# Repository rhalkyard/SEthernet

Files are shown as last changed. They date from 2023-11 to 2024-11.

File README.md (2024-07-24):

# SEthernet and SEthernet/30

Modern, low-cost 10/100 Ethernet for the Macintosh SE and SE/30.

## Introduction

It's an unfortunate reality of retrocomputing that, as time goes on, original
hardware only ever becomes more scarce, and usually more expensive.

While PDS ethernet cards are certainly not _scarce_ yet, the collector appeal of
Compact Macs means that cards are in high demand, with consequent high prices.
As of this writing (October 2023), the going eBay rate for them seems to be of
the order of $US 150-200, which is a bit steep for those of us who remember
finding them in electronics-recycler dollar bins.

While other projects have aimed to clone these original cards, such an approach
comes with a downside - the ethernet controller chips used in them have been out
of production for many years, and the controllers and (even more so) their
supporting components, are difficult to find.

While cloned cards trade off parts sourcing difficutly (and cost) for the
significant advantage of being able to use existing drivers, this project takes
the opposite approach: design an all-new card using a modern, readily-available
ethernet controller, and write a new driver for it. How hard can it be?
[^howhard]

## Hardware Overview

Both the SEthernet and SEthernet/30 use the Microchip
[ENC624J600](https://ww1.microchip.com/downloads/aemDocuments/documents/OTH/ProductDocuments/DataSheets/39935c.pdf)
all-in-one embedded ethernet controller. It's cheap, readily available, has a
straightforward software interface without too many glaring misfeatures (I'm
looking at you, RTL8019AS), and amongst its multitude of configurable host-bus
modes, it has one that matches the 68k processor bus nicely.

Since the Macintosh SE lacks any real infrastructure for expansion beyond
"here's a connector with the CPU bus on it," the SEthernet board is a very dumb
device. It simply maps the ENC624J600 into a vacant chunk of memory at `0x80
0000`-`0x80 ffff` and connects it to an interrupt line. Hardware detection,
interrupt vector interception, and device configuration are all left to the
driver to implement.

The Macintosh SE/30 is a more civilised machine, and the SEthernet/30 provides a
[declaration ROM](rom/se30) and multiple addressing options (configurable by
jumper) to take full advantage of the Slot Manager and coexist with multiple PDS
cards. Potentially, the driver could even be built into the declaration ROM,
allowing for a truly plug-and-play solution. To facilitate driver updates, the
declaration ROM is a flash chip, with logic to allow for in-system programming.

## Current project status

### Hardware

Hardware Revision 1 is largely 'done', and corrects the numerous issues of my
initial "Revision 0" boards. A few mechanical tweaks remain to get mounting
holes in exactly the right spot, and relocate connectors for easier access.

### Software

The core driver is functional and stable enough for everyday use. Real-world
performance is marginally better than a comparable vintage card, but there is
likely room to improve - especially in the rather convoluted receive routine.

Support for promiscuous mode, and the `ERead` call are not yet implemented.

The installer has some rough edges (no hardware detection or driver version
detection on the SE), but functions as a way to get drivers onto a system.

The SE/30 board's Declaration ROM must be programmed before the card can be
recognized. This can be done in-system using the
[programROM](software/tools/programROM/) application provided on the installer
disk, but right now this is a very ugly and user-unfriendly console application,
and really should be turned into a proper GUI app.

Testing has been done on my unmodified SE and SE/30 under Systems 6.0.8, 7.1,
and 7.5.5.

A driver for A/UX 2 and 3 can be found at
https://github.com/rhalkyard/SEthernet-AUX. 

## Project files

Schematics: [SEthernet](boards/se/se.pdf) -
[SEthernet/30](boards/se30/se30.pdf) - [Breakout Board](boards/breakout/breakout.pdf)

Glue Logic: [SEthernet](pld/se) - [SEthernet/30](pld/se30)

[SEthernet30 Declaration ROM](rom/se30)

[Driver](software/driver)

## Required tools

### Schematics, board layout and BOM

[KiCad 7](https://www.kicad.org/)

### Programmable Logic

[WinCUPL and ATMISP](https://www.microchip.com/en-us/products/fpgas-and-plds/spld-cplds/pld-design-resources)
(see [`pld/README.md`](pld/README.md) for notes on WinCUPL)

### Declaration ROM, driver and software

- [Retro68](https://github.com/autc04/Retro68) built with [Apple Universal
  Interfaces](https://github.com/autc04/Retro68#apple-universal-interfaces-vs-multiversal-interfaces)
  (at the time of writing, the default free-software Multiversal Interfaces do
  not include some necessary headers)

- [CMake](https://cmake.org/)

- [Python 3](https://www.python.org)

### Installer

- [hfsutils](https://www.mars.org/home/rob/proj/hfs/)

- [Python 3](https://www.python.org)

- [Mini vMac](https://www.gryphel.com/c/minivmac/index.html)

## License

The hardware components of this project ([board designs](boards/) and
[programmable logic](pld/)) are licensed under the [Strongly-Reciprocal CERN
Open Hardware License, version 2](CERN-OHL-S-2.0).

The [software components](software/) of this project are licensed under the [GNU
General Public License v3.0](COPYING).

While my choice to make this project open-source is very much a deliberate one,
I have a few further requests, on the basis of "I can't and won't enforce these,
but I'd appreciate if you respected them." It's unfortunate that I have to
mention this, but given how a few recent projects in the retro-hardware
community have splintered, I feel that it's necessary to say:

- Please don't sell cards commercially/for profit without checking with me
  first. I have plans for a sales and manufacturing partnership that will sell
  boards affordably, with full support. I don't mind if you order a batch of
  boards for yourself and sell the extras on a break-even basis, but please make
  it clear that these are not 'official' SEthernet products.

- Please contribute back, rather than simply forking the project. I strongly
  encourage people to modify the design, adapt it to other systems, integrate it
  into other devices. But unless what you're working on is a radical departure
  from the basic SEthernet design, I'd much rather see a unified, collaborative
  effort that is supported by a single software stack, rather than having it be
  fragmented.

If you have any questions, feel free to reach out to me, I don't bite!

## Useful reference material

- [ENC624J600 datasheet](https://ww1.microchip.com/downloads/aemDocuments/documents/OTH/ProductDocuments/DataSheets/39935c.pdf)

- [Designing Cards and Drivers for the Macintosh Family (3rd
  Edition)](https://www.vintageapple.org/inside_o/pdf/Designing_Cards_and_Drivers_for_the_Macintosh_Family_3rd_Edition_1992.pdf)

- [Inside Macintosh (1994): Networking](https://www.vintageapple.org/inside_r/pdf/Networking_1994.pdf)

- [Inside Macintosh (1994): Devices](https://www.vintageapple.org/inside_r/pdf/Devices_1994.pdf)

- [Glenn Anderson's ethernet driver page](https://www.mactcp.net/ethernet.html) -
  contains C source for a DP8390-based card.

- [Mac Driver Museum: Network
  Drivers](https://vintageapple.org/macdrivers/network.shtml) - good material
  for reverse-engineering. In particular, the Dayna ethernet drivers contain
  debug symbols, which are quite handy for our purposes.

- [Rob Braun's declaration ROM page](http://www.synack.net/~bbraun/declrom.html)
  has useful information about declaration ROMs and how they work.

[^howhard]: [Arrested Development narrator voice]: It was, in fact, quite hard

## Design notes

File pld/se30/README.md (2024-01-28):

# PLD Equations for 68030 PDS Interface

U3 on the SEthernet/30 board is an ATF1502 Complex Programmable Logic
Devices that provides address decoding and glue logic.

## Address Decoding

The SEthernet/30 board uses a Nubus 'pseudo-slot' design, occupying an address
corresponding to a NuBus slot, and appearing to the Slot Manager just like a
NuBus card would on a workstation Mac. To allow for multiple expansion cards,
jumpers JP1 and JP2 can be used to configure the card to act as though it is
installed in slots 9, A, B, or E.

Each slot has an interrupt line dedicated to it on the PDS connector, U3 routes
the ENC624J600's interrupt to the appropriate line based on the selection made
on JP1 and JP2.

Within the card's address space, minimal decoding is performed on address line
A16, so that the card's declaration ROM shows up at the top of the address space
(as expected by the Slot Manager), with the ENC624J600's address space
immediately below it.

Note that the Slot E configuration is not compatible with the SE/30 or IIsi.
This option exists to allow the card to be used in the PDS slot of a Macintosh
IIfx. This configuration has been tested and works, but the IIfx case does not
provide a place to mount the breakout board.

## Bus Control

While the ENC624J600 in PSP Mode 4 maps neatly onto the 68000's control lines,
glue logic is required to interface with the 68030. Page 7-26 of the [M68030
User's Manual](https://www.nxp.com/docs/en/reference-manual/MC68030UM-P1.pdf)
describes logic to interface the 68030 to peripherals using 68000-style
byte-select lines, a 16-bit subset of which is implemented in U4.

Additionally, U4 generates the `/DSACKx` signals for the 68030 bus handshaking
scheme. To accommodate the timing characteristics of the ENC624J600 (75 ns from
selection to data valid on read), a counter is used to delay assertion of
`/DSACKx` for 1 or 2 clock cycles after the chip is selected.

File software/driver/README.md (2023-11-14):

# Driver

The source this directory can build a Slot Manager `.ENET` driver for an SE/30
card, or a non-Slot Manager `.ENET0` driver for an SE card.

While the code for the two drivers is identical save for some differences in
device initialization and interrupt handling, the way Mac OS ethernet drivers
work means that they need to be separate driver resources.

## SEthernet/30

Slot Manager drivers such as the SEthernet/30 driver use `.ENET` as the driver
name in their resource header, and are installed as `enet` resources with a
Resource ID corresponding to the Board ID that they operate with. These drivers
can either be installed directly into the System File, or (with Network Software
Installer 1.5 or later) as Extensions with the type `comd`.

When an ethernet device is opened with `OpenSlot()`, the system `.ENET` 'driver
shell' searches `enet` resources for a driver whose resource ID matches the
Board ID of the slot, and loads that driver instead.

## SEthernet

Non-Slot Manager drivers must be installed as traditional drivers (i.e. a `DRVR`
resource) called `.ENET0`. This can either be done by manually installing the
resource into the System file, or loading the driver into the driver table at
run-time, for example, using an `INIT`.

Software that uses ethernet devices must try to load a `.ENET0` driver if no
Slot Manager devices are available. See Listing 1-11 in [IM:
Networking](https://www.vintageapple.org/inside_r/pdf/Networking_1994.pdf) for
details (and "Installing a Device Driver" in [IM:
Devices](https://www.vintageapple.org/inside_r/pdf/Devices_1994.pdf) for the
absurd song-and-dance routine that is installing and opening a device driver).

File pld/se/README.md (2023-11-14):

# PLD Equations for 68000 PDS Interface

U2 on the SEthernet board is an ATF16V8/GAL16V8 programmable logic device that
provides address decoding and miscellaneous glue logic.

Address decoding is straightforward - when `/AS` is asserted and address lines
`A24..A16` indicate an address in the range `0x80 0000`-`0x80 FFFF`, we assert
the ENC624J600's chip-select pin.

Glue logic is also minimal - the `B0SEL` and `B1SEL` byte-select lines on the
ENC624J600 are just active-high equivalents to the active-low `/UDS` and `/LDS`
lines on the 68000 bus. The BBU chip on the SE logic board automatically asserts
`/DTACK` for us on a schedule that we can live with, so there is no need to
generate it ourselves (if we needed additional wait states, we could assert
`/EXT.DTK` to suppress the BBU's `/DTACK` signal until we were ready).

Finally, the push-pull interrupt output of the ENC624J600 is buffered and turned
into an open-drain output, allowing it to interface with the wired-OR interrupt
logic of the SE.

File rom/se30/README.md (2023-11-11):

# Declaration ROM

To make use of the Slot Manager for hardware probing, interrupts, etc. we need
to do two things:

- Map our device into a memory region corresponding to a NuBus slot (on the
  SE/30, valid 'pseudoslots' are `9`, `A`, or `B`).

- Have a declaration ROM header at the very end of the slot's address space,
  pointing to a valid sResource directory.

This directory contains a suitable declaration ROM laid out in GNU Assembler
format, with a Python script to perform some basic validity checks and
post-processing.

## Files

`declrom.s`: Source for declaration ROM.

`ROMDefs.inc`: Assorted constants and macros for declaration ROMs, converted to
GNU Assembler format from Universal Interfaces file `AIncludes/ROMDefs.a`.

`declrom_macros.inc`: Additional macros for declaration ROMs.

`gencrc.py`: Quick 'n dirty Python script to sanity-check a declaration ROM
header, calculate and write the CRC field, and pad it to a suitable length to
program into an EPROM.

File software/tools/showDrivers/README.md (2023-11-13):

# showDrivers

A quick and dirty tool to list the entries in the system's driver table.

## Table columns

**Unit**: Driver unit number

**RefNum**: Driver reference number used for Device Manager calls (1's complement
of unit number)

**Flags**: Driver flags (explained below)

**DRVRAddr**: Address of driver's `DRVR` resource in memory

**Name**: Driver name

## Driver flags

Lowercase letter means flag is not set, uppercase letter means flag is set.

**L**: Driver is locked in memory

**T**: Driver performs periodic tasks

**G**: Driver needs to be called before application heap initialization

**S**: Driver responds to `Status` call

**C**: Driver responds to `Control` call

**W**: Driver responds to `Write` call

**R**: Driver responds to `Read` call

**A**: Driver is currently executing a request

**H**: Driver is referenced through a Handle, rather than a Pointer

**O**: Driver is open

**V**: Driver has marked itself as virtual-memory safe

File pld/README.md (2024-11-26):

# Programmable Logic Device Sources

The sources in this dirctory are in CUPL format, and can be built using the
Windows-based
[WinCUPL](https://www.microchip.com/en-us/products/fpgas-and-plds/spld-cplds/pld-design-resources)
software. Unfortunately, using WinCUPL is a retrocomputing exercise in its own
right - the GUI does not work on anything newer than Windows XP.

However, it is possible to run WinCUPL under Wine, and the CMake monstrosity in
this directory uses Wine and WinCUPL to build CUPL sources without having to
mess with Windows XP. It looks for WinCUPL in `~/.wine/drive_c/Wincupl`, which
is the default installation path. If your Wine data is in a different place, or
you installed WinCUPL elsewhere, the `WINCUPL_PATH` cache variable will need to
be set to point to the correct location. If Wine and/or Wincupl are not
available, then the PLD build target is skipped.

The typical WinCUPL workflow is to then use the ATMISP software to either drive
an Atmel/Microchip programmer directly, or generate an SVF file that can be used
by a generic JTAG programmer. This workflow, frankly, stinks, and we instead use
the `fuseconv` utility from [prjbureau](https://github.com/whitequark/prjbureau)
to generate an SVF. Setup of prjbureau is automatic, but Python 3 and the
`virtualenv` module are required.

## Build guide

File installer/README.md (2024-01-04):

# Installer

## Building an installer

You will need:

- [hfsutils](https://www.mars.org/home/rob/proj/hfs/)

- [Python 3](https://www.python.org)

- [Mini vMac](https://www.gryphel.com/c/minivmac/index.html)

- A relatively modern (4.0 or newer) version of the Bash shell

Build the SEthernet source tree as per usual, and then run `build.sh`, giving it
the location of the build tree, and the name of the disk image to produce, e.g.
`./build.sh ../build install.dsk`. The build script will launch MPW within Mini
vMac, build an installer disk image, and (hopefully) quit without any
intervention. If something goes wrong, Mini vMac will remain open, and the MPW
Worksheet will show the diagnostic output from the build. Good luck figuring it
out!

## Files

### Installer resources
- `atoms.r`: Specifications for installer 'atoms' - an atom can add or remove a
  file (`infa`) or a resource (`inra`), or run custom-code 'actions' at install
  time (`inaa`)

- `code.r`: Code resources run by action atoms and install rules

- `comments.r`: Installer 'comments' providing information about install
  packages

- `filespecs.r`: Specifications of source and destination files, referenced by
  file and resource atoms

- `misc.r`: Miscellaneous resources not directly referenced by the Installer

- `packages.r`: Packages are collections of atoms that can be selected either
  automatically by rules, or manually through the Custom Install interface

- `rules.r`: Rules processed at startup that select a default set of packages

### Build System

- `Build.mpw`: MPW shell script that compiles the Installer script resources and
  post-processes them with ScriptCheck

- `UserStartup.mpw`: MPW UserStartup script used to trigger autommated builds

- `build.sh`: Bash script that automates the installer build process using Mini
  vMac

- `text2mac.py`: Helper script to convert line endings and encodings of text
  files

- `images/buildenv.dsk.gz`: Build environment - System 6.0.8, MPW 3.1, Installer
  SDK 3.4

- `images/template.dsk.gz`: Installer disk template - contains AppleTalk support
  components from Network Software Installer 1.4.4, and Installer application.

### Output files

- `installer.dsk.gz`: SEthernet install disk

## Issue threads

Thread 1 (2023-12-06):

Rev0 schematics and boards configure ENC624J600 for SPI operation

rhalkyard, 2023-12-06:
The Revision 0 schematics and boards pull the `/INT`-`SPISEL` pin up, instead of down. This causes the ENC624J600 to come up in SPI mode, which is rather useless for our purposes.

## Workaround
Pull `SPISEL` down by cutting the 3.3V supply to the `SPISEL` pullup resistor (10K, R5 on SEthernet, R2 on SEthernet/30), and connecting the resistor to ground instead.

rhalkyard, 2024-02-17:
Resolved in rev1

Closed 2024-02-17.

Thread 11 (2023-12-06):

Create runnable installer

rhalkyard, 2023-12-06:
While the SEthernet/30 driver is just a file that you can drop into your Extensions folder, the SEthernet driver cannot work this way, and must be installed as a `DRVR` resource into the System file (since the Extension loading mechanism appears to require the Slot Manager). This is easy enough to do with ResEdit, but it's an ugly thing to have to put into the installation instructions.

The [Apple Installer SDK](https://macintoshgarden.org/apps/apple-installer-sdk) is available on the Macintosh Garden. It looks hideously convoluted, but it'd be neat to leverage that to create a runnable installer like a real product would have.

rhalkyard, 2024-01-05:
https://github.com/rhalkyard/SEthernet/commit/cda505bcd17a0819d6cadd70a49d3d6ab575ed57 sets up a basic installer framework based on Network Software Installer 1.4.4, currently capable of installing the SEthernet/30 driver and installing/updating AppleTalk and EtherTalk support.

Closed 2024-01-05.

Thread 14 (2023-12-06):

Driver is broken

rhalkyard, 2023-12-06:
As far as I have been able to test on the SEthernet/30 board that I have built, the driver is largely complete. It loads successfully, and passes MacTCP traffic without error. However, it appears to cause crashes when handling AppleTalk traffic - the system goes off into the weeds, with stack corruption obscuring where things actually went wrong.

Needless to say, this is suboptimal.

Just based on when the crash appears to occur (right after the first time a DDP packet is received), the prime suspect is the [`ReadPacket`/`ReadRest` routine](https://github.com/rhalkyard/SEthernet/blob/main/software/driver/readpacket.S), which is passed as a callback to protocol handlers, but it's not obvious where it's going wrong.

rhalkyard, 2023-12-12:
Disabling async transmit in https://github.com/rhalkyard/SEthernet/commit/098e213cfae7d963cd8ab3f9696ad677128cea29 appears to have gotten the driver mostly working. Still need to figure out what's going wrong with transmit completions, but it's something at least.

rhalkyard, 2023-12-15:
Commit https://github.com/rhalkyard/SEthernet/commit/1edbe0d948d3d2b33f1e27dbd1d209e88dc15bca appears to have fixed this issue and got the driver working correctly with async transmit enabled. The root causes were twofold:

- `IODone` may trash additional registers beyond those that the standard C calling conventions expect, which was causing all sorts of strange behavior that changed depending on optimization levels. This does not appear to be documented in Inside Macintosh, but the source code in the 'SuperMario' source leak makes it clear (specifically, the `PostCompletion` routine called by `IODone`): https://github.com/elliotnunn/supermario/blob/9dd3c4bef84df2ea30f5ec2c5e97b043e8267b3f/base/SuperMarioProj.1994-02-09/OS/DeviceMgr.a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

- I was acknowledging transmit interrupts _after_ calling `IODone`. This could lead to a condition where a completion handler would issue another `EWrite` call, which would finish before `IODone` returned, causing its completion interrupt to be lost. Interrupts must be acknowledged _before_ calling `IODone`

Closed 2023-12-15.

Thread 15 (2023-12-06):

Build and test card for Macintosh SE

rhalkyard, 2023-12-06:
The original plan was to bring up the SEthernet card on a Macintosh SE first, as its hardware is simpler. However, my SE suffered a hard disk failure and has been out of action, so I've focused my Rev0 bringup efforts on the SEthernet/30 card for the SE/30. This has largely been a success (save for some hardware bugs that can be worked around).

At some point before making boards available, I should still make sure the SEthernet board works though.

rhalkyard, 2023-12-18:
This is likely not going to happen until Rev1 hardware. After assembling an SE board I noticed that I'd got the PDS connector pinout backwards (https://github.com/rhalkyard/SEthernet/issues/17).

This theoretically could be worked around by putting the connector on the 'wrong' side of the board, but I really don't feel like desoldering a 96 pin through-hole connector, and I don't have enough parts to make up another board.

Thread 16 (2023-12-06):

Suggest supporting surface-mount PLCC sockets

terrabite3, 2023-12-06:
I'm currently using surface-mount PLCC sockets for a project, specifically this one:

https://www.mouser.com/ProductDetail/575-946817

I've found that the footprint of the socket is the same as for soldering a PLCC directly to the board, except that it requires more space around the pads. If it's feasible, I suggest leaving room so that you or others will have the option of using this type of socket.

I'm not likely to build this myself, so I don't have any skin in the game. I just wanted to pass on a tip in case it might be useful.

rhalkyard, 2023-12-06:
Thanks! I thought about it, but I've always found them tricky to hand-solder, and Revision 0 was only ever intended to be a prototype that I could throw together myself to prove the concept out before cleaning the design up for production.

For my next revision of the board, I plan to ditch the GALs for a JTAG-programmable CPLD (#5), and write a tool to reflash the declaration ROM in-system (#6), so no sockets will be required - this will have the added benefit of making automated assembly (e.g. by JLCPCB's assembly service) much easier, since it won't require any preprogrammed parts.

Closed 2023-12-06.

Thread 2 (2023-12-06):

ENC624J600 does not meet timing specs for SEthernet/30 read accesses

rhalkyard, 2023-12-06:
The 68030 PDS bus is too fast for the ENC624J600. This causes card behavior to be erratic, with read operations returning invalid data.

## Workaround

Add an additional GAL to insert wait states.

- Carefully cut the traces connecting U4 pin 4 to ground on both sides of the board (a small countersink bit works well for this).

- Program a GAL16V8/ATF16V8 with the equations in [`pld/se30/se30-bodge.pld`](pld/se30/se30-bodge.pld) and 'dead bug' it to a convenient place on the circuit board, connected as follows:

Pin #  | Destination
-------|------------
1      | U1, pin 33 (`CLKOUT`) or J1, pin c38 (`C16M`/`CPUCLK`) (see note below)
2      | U3, pin 12 (`!ROM_CS`)
3      | U3, pin 13 (`EN_CS`)
10, 11 | Ground
12     | U4, pin 4 (`WAIT`)
20     | +5V

Connect a 0.1uF capacitor across pins 10 and 20.

It is preferable to use the ENC624J600's software-configurable `CLKOUT` pin as a clock source, but the clock signal available on pin c38 of the PDS connector (16MHz `C16M` on the SE/30 and IIsi, 20MHz `CPUCLK` on the IIfx) can be used as a more easily-soldered alternative.

The default `CLKOUT` frequency of 4MHz (`COCON`=`1011`) gives ample timing margin, 25MHz (`COCON`=`0010`) gives
an optimal wait-state delay of 80 nanoseconds.

rhalkyard, 2024-02-17:
Resolved in rev1 CPLD-based glue logic

Closed 2024-02-17.

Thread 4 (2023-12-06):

ENC624J600 may generate spurious interrupts when system is restarted

rhalkyard, 2023-12-06:
Because the ENC624J600 has no hardware reset input, spurious interrupts may be generated on a warm restart if the link state changes or packets are received. This may cause a Sad Mac or a System Error during early boot.

##### Workaround

Shut the Mac down fully and cold-boot it, or disconnect the ethernet cable before warm-restarting and only reconnect it after the driver has loaded.

If the system has crashed, the MacsBug command `sm <base-address>+7f6e 1000;rb` (where `<base-address>` is the card base address) will reset the ENC624J600 to put it into a safe state, and then reboot the system.

rhalkyard, 2023-12-12:
Commit f1a081a has a Shutdown Manager procedure that resets the ENC624J600. It won't help with a reset after a crash, but it works for the "clean restart" case.

rhalkyard, 2024-02-17:
Resolved in CPLD-based glue logic for rev1 - interrupts are disabled until the ENC624J600 has been written to 3 times to indicate that the driver is in control.

rhalkyard, 2025-02-07:
This did not work as planned, and spurious interrupts still sometimes seem to be getting through. Additionally, the lack of reset means that the ethernet chip is left in a 'running' state when booting into an environment that lacks a driver for it. This will cause it to continuously assert flow control once the receive buffer fills up, which is a bit un-neighborly.

Instead I'm working on a modified power supply arrangement that powers the ENC624J600 down on reset, and does not power it on until a positive action is taken by the driver to enable it. This will have the effect of power-on-resetting the chip at every reset, which is what we could have had all along if it had just had a reset pin.

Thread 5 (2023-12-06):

Move glue logic to CPLD

rhalkyard, 2023-12-06:
Moving glue logic from GALs to a CPLD will be advantageous in several ways:

* Reduce the SEthernet/30's 3 glue-logic GALs into 1 chip
* Allow for in-system programming of glue logic via JTAG
* More gates will allow for more sophisticated glue logic (in particular, mitigations for #2, #3 and #4)

The [ATF1502AS](https://www.microchip.com/en-us/product/atf1502as) looks like a suitable candidate - it's cheap, in production, works at 5V logic levels, and is compatible with the CUPL toolchain I have been using for the GALs.

rhalkyard, 2024-02-17:
Done in rev1

Closed 2024-02-17.

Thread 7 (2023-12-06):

Rework design for automated manufacturing

rhalkyard, 2023-12-06:
JLCPCB have a very affordable PCB-assembly service. Rework the design to support this:

- Add BOM part numbers for JLC's part library
- Optimize part selection for cost and availability from JLC
- Eliminate through-hole parts and IC sockets where possible
- Eliminate requirement for pre-programmed parts (see #5 and #6)

rhalkyard, 2024-02-17:
While boards have not been ordered through an assembly service yet, rev1 should be good to go for automated manufacturing.

Closed 2024-02-17.

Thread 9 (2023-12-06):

SEthernet/30 extension icon is broken

rhalkyard, 2023-12-06:
The SEthernet/30 extension's Finder resources are broken. It gets recognised as an extension, but shows up as a "Document" file with no icon. This should get fixed.

rhalkyard, 2023-12-17:
Turns out that the system provides an icon for ethernet driver extensions without having to do anything special. Adjusted our creator code to use that mechanism, rather than trying to bring our own icon.

Closed 2023-12-17.

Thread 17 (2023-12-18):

SE PDS pinout is backwards on Rev0

rhalkyard, 2023-12-18:
Revision 0 SEthernet boards have the SE PDS pins numbered from the wrong end. This causes the machine to fail to power on with the card installed, due to a short between +12V and ground.

It should be possible to install the connector on the other side of the board to get the correct pinout, but clearances may become an issue. Probably just going to put the SE on hold until rev1.

rhalkyard, 2024-02-17:
Resolved in rev1

Closed 2024-02-17.

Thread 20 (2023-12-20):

Wait for link to come up after reset

rhalkyard, 2023-12-20:
When the driver is opened, the ENC624J600 is reset, which causes the link to be interrupted. While the time for the MAC and PHY to come back after a reset is defined in the datasheet and accounted for in the driver, the time for a link to be reestablished is not (and probably depends on too many external parameters to really ever define). Judging by the time between the link light going out and coming back on again, I'd guess it's of the order of 0.5-1 second.

It's only natural for software to open the driver and then immediately begin transmitting packets, and this is exactly what happens during boot - the driver is opened, and then AppleTalk sends out a bunch of 'who has this address?' AARP packets as part of its address-assignment algorithm.

The ENC624J600 seems to be perfectly happy to 'transmit' a packet on a down link, and reports success in doing so, but even when checking for link state and failing the transmit in software, those packets are simply lost - it seems as though AppleTalk simply sends some number of packets and does not check how many succeeded or not.

Depending on how long the link takes to come up, this means that either some of the 'who has' packets are dropped (not ideal, but so long as one gets through, address assignment should work as it should), or all of them are dropped, which could potentially result in the computer taking an already-in-use address.

As mentioned above, failing transmission on a down link does not seem to be enough - either we should wait for the link to come up as part of the reset process, or *queue* transmits on a down link (rather than failing them) and only actually send them when a link comes up. Both of these options have associated issues in handling the case of a link not being there at all, but it's probably better to add some complexity to deal with that, rather than potentially breaking AppleTalk address assignment.

rhalkyard, 2023-12-25:
Adding a fixed 1.5 second delay after resetting the chip seems to give enough time for the link to come up, but that's a pretty crude way to deal with it.

Really, we should probably do something like check the link state before reset, and if we have a link, wait for some amount of time for it to come back up, otherwise just continue on without waiting.

rhalkyard, 2024-01-05:
Thinking about it some more, a fixed delay is probably the best solution that we have available - queueing transmits could go very badly for us if we never get a link, and checking link status before reset would add complexity for little gain.

Closed 2024-01-05.

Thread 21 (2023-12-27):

Driver does not appear to be compatible with Classic Networking on System 7.5.3

rhalkyard, 2023-12-27:
On a fresh install of System 7.5.3 on my SE/30, the SEthernet/30 card does not appear in the Network control panel, even though it *is* available in the MacTCP control panel and works as it should under TCP/IP.

Switching to Open Transport allows the card to be selected and function for both TCP/IP and AppleTalk, but since 7.5.3 defaults to Classic Networking, it'd be nice to be able to support it 'out of the box'.

rhalkyard, 2023-12-27:
Same thing on 7.5.5, and after updating to Open Transport 1.1.2

rhalkyard, 2023-12-29:
After installing the EtherTalk NB drivers from Network Software Installer 1.5.1, The SEthernet/30 driver now works fine on Classic Networking as well as Open Transport on 7.5.5.

Will need to investigate this dependency as part of the installer (#11) and/or documentation (#10).

Closed 2023-12-29.

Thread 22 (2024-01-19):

ENC624J600 requires delay between chip-select and byte-select

rhalkyard, 2024-01-19:
Per the ENC624J600 datasheet, there must be a couple of nanoseconds' delay between asserting `CS` and byte strobes `B0SEL`/`B1SEL` (T<sub>PSP1</sub> and T<sub>PSP5</sub> in the attached charts).

For write cycles, this is not a problem, since the 68k asserts its data strobes (from which we derive `B0SEL`/`B1SEL`) 1 clock after `/AS` (from which we derive `/CS`).

However, in read cycles, the 68k asserts data and address strobes simultaneously, meaning that we need to create this delay ourselves. In rev0, this is achieved by having a GAL propagation delay between the `CS` and `B0SEL`/`B1SEL` outputs - for the SE/30 card, this comes as a side effect of having multiple GALs in the glue logic. For the SE card, this was achieved by use of a feedback pin instead of an internal logic term (see https://github.com/rhalkyard/SEthernet/commit/c221345f229c730390ce27fa9238d6dc023339f9).

For the CPLD-based logic proposed in #5, this will need to be taken into account somehow. Adding an extra round-trip through the CPLD is probably more delay than we want, so another option would be to add a logic gate between the CPLD and the ENC624J600 to insert a small delay - the [74LVC2G17](https://assets.nexperia.com/documents/data-sheet/74LVC2G17.pdf) dual non-inverting buffer looks to be a suitable candidate, with a propagation delay of 1.0-4.3ns at V<sub>CC</sub>=5V.

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

rhalkyard, 2024-02-17:
Rev1 incorporates a buffer as described above, but this did not introduce sufficient delay for reliable operation. Ensuring a round-trip through the CPLD provides sufficient delay without the buffer.

Closed 2024-02-17.

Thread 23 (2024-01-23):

Add APIs for ENC624J600 cryptography engine

rhalkyard, 2024-01-23:
The ENC624J600 has a hardware cryptography engine that can do modular exponentiation, and calculate MD5 and SHA1 digests (the datasheet also says it does AES, but the errata indicates this is buggy and should not be used).

There seems to be [some interest](https://68kmla.org/bb/index.php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) in adding support for modern TLS to the classic Mac OS, and even a [working implementation](https://github.com/leitec/polarssl-macos), but it sounds as though offload is the only practical way this could be achieved on 68k machines.

Additional `Control` calls could be added to the driver to expose this functionality to applications.

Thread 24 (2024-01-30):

Handle missed interrupts more gracefully

rhalkyard, 2024-01-30:
Inside Macintosh warns strongly against doing synchronous IO at interrupt time, since this can cause interrupt-driven drivers (such as ours) to deadlock.

Unfortunately, some software does this - such a deadlock can easily be replicated by attempting to mount a large (>300MB) disk image in Disk Copy 6.3 - after mounting the image, the system locks up inside a synchronous IO call which never completes because interrupts are masked. This issue is not specific to the SEthernet driver - the exact same lockup occurs using an Asante MacCon NuBus card on a Mac IIfx with Apple's own drivers.

However, it should be possible to handle this in a more graceful fashion and recover from it - in the Disk Copy case, manually failing the IO call in MacsBug (by setting the parameter block's return code to -1) unblocks the system and everything proceeds as normal (presumably the IO operation gets retried or something).

A possible solution could be to establish a timeout for interrupt handling, after which all pending IO would be failed. This in turn would require that the interrupt handler to run as a Deferred Task, so that it could be interrupted by a Time Manager task handling the timeout. Care would need to be taken to keep the driver and hardware in a sane state through this, but it should be at least somewhat more robust than having the system hang.

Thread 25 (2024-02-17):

SEthernet/30 Rev1: Connector to breakout board fouls on hard drive cage

rhalkyard, 2024-02-17:
On Revision 1 of the SEthernet/30 board, the 8-way connector to the breakout board is positioned in such a way that it fouls the hard drive cage.

This connector should be either relocated, or replaced with a right-angle connector with a lower profile.

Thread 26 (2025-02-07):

Feature Request: Horizontal / 3rd PDS Slot for passthrough for accelerator (ala Bolle Ethernet)

grumpymaker, 2025-02-07:
It would be amazing to have a horizontal takeoff PDS slot similar to the one on Bolle's Ethernet card.  This would allow usage of an accelerator in the horizontal position and allow for the top card stack to be one of the Grayscale cards out there.

I know this is an extremely popular combination on the SE/30 community (namely, Bolle Ethernet combo + Grayscale + Carrera040 or similar).

I have a Zigzagjoe Grayscale Card that I would love to combine with this and be able to optionally stack in an accelerator in the future.

I'm not sure if this is feasible, but I would be happy to try banging my head against it a bit if anybody has an idea of what would be required electrically.

rhalkyard, 2025-02-07:
Thanks for the feedback! I did give some thought to doing things that way, but there a few reasons I didn't - for one, I don't have any such accelerators to test fit and compatibility with, and can't really justify the expense of acquiring them. Additionally, having built a few ethernet cards up, I've become less convinced that the 'tall' form factor is the way to go. It makes for an unnecessarily large board, which increases the production cost, and the long signal runs seem to introduce signal-integrity issues that I'm not really smart enough to resolve.

If I understand correctly, the side-mounted slot on Bolle's card isn't a direct connection to the PDS slot. I think it's meant to take IIci cache cards, with logic on the board to interface it to the rest of the bus, but that's Bolle's secret recipe and I'm not sure what it actually involves. No reason why you couldn't just put a second PDS slot there instead of a cache slot, I suppose, but signal integrity might become even more of a problem - in particular the 16MHz clock gets pretty nasty, and the rise-times on the open-collector `/DSACK` lines can be problematically slow, especially with a accelerator thrown into the mix (I run a Zigzagjoe processor-socket accelerator, and slow-rising `/DSACK` plays havoc with it).

I do have a revised design in the works, where I've ditched the tall form-factor in favour of the lower profile used by most original ethernet cards and the Zigzagjoe grayscale card. This should make the card compatible with the IIsi, and also be more amenable to stacking up multiple cards with pass-through slots. The revised design also incorporates buffering to try to deal with the signal-integrity issues, and fixes a couple of minor hardware bugs.

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

I'll admit that this project has fallen by the wayside a bit - between other projects, life events, and the uncertain situation with China-US shipping and tariffs, I haven't yet pulled the trigger on a new batch of boards. If you're still keen on the idea of a horizontal-slot version, I'd be happy to help out with the design process - this would be good motivation for me to clean up my work-in-progress and get it uploaded!

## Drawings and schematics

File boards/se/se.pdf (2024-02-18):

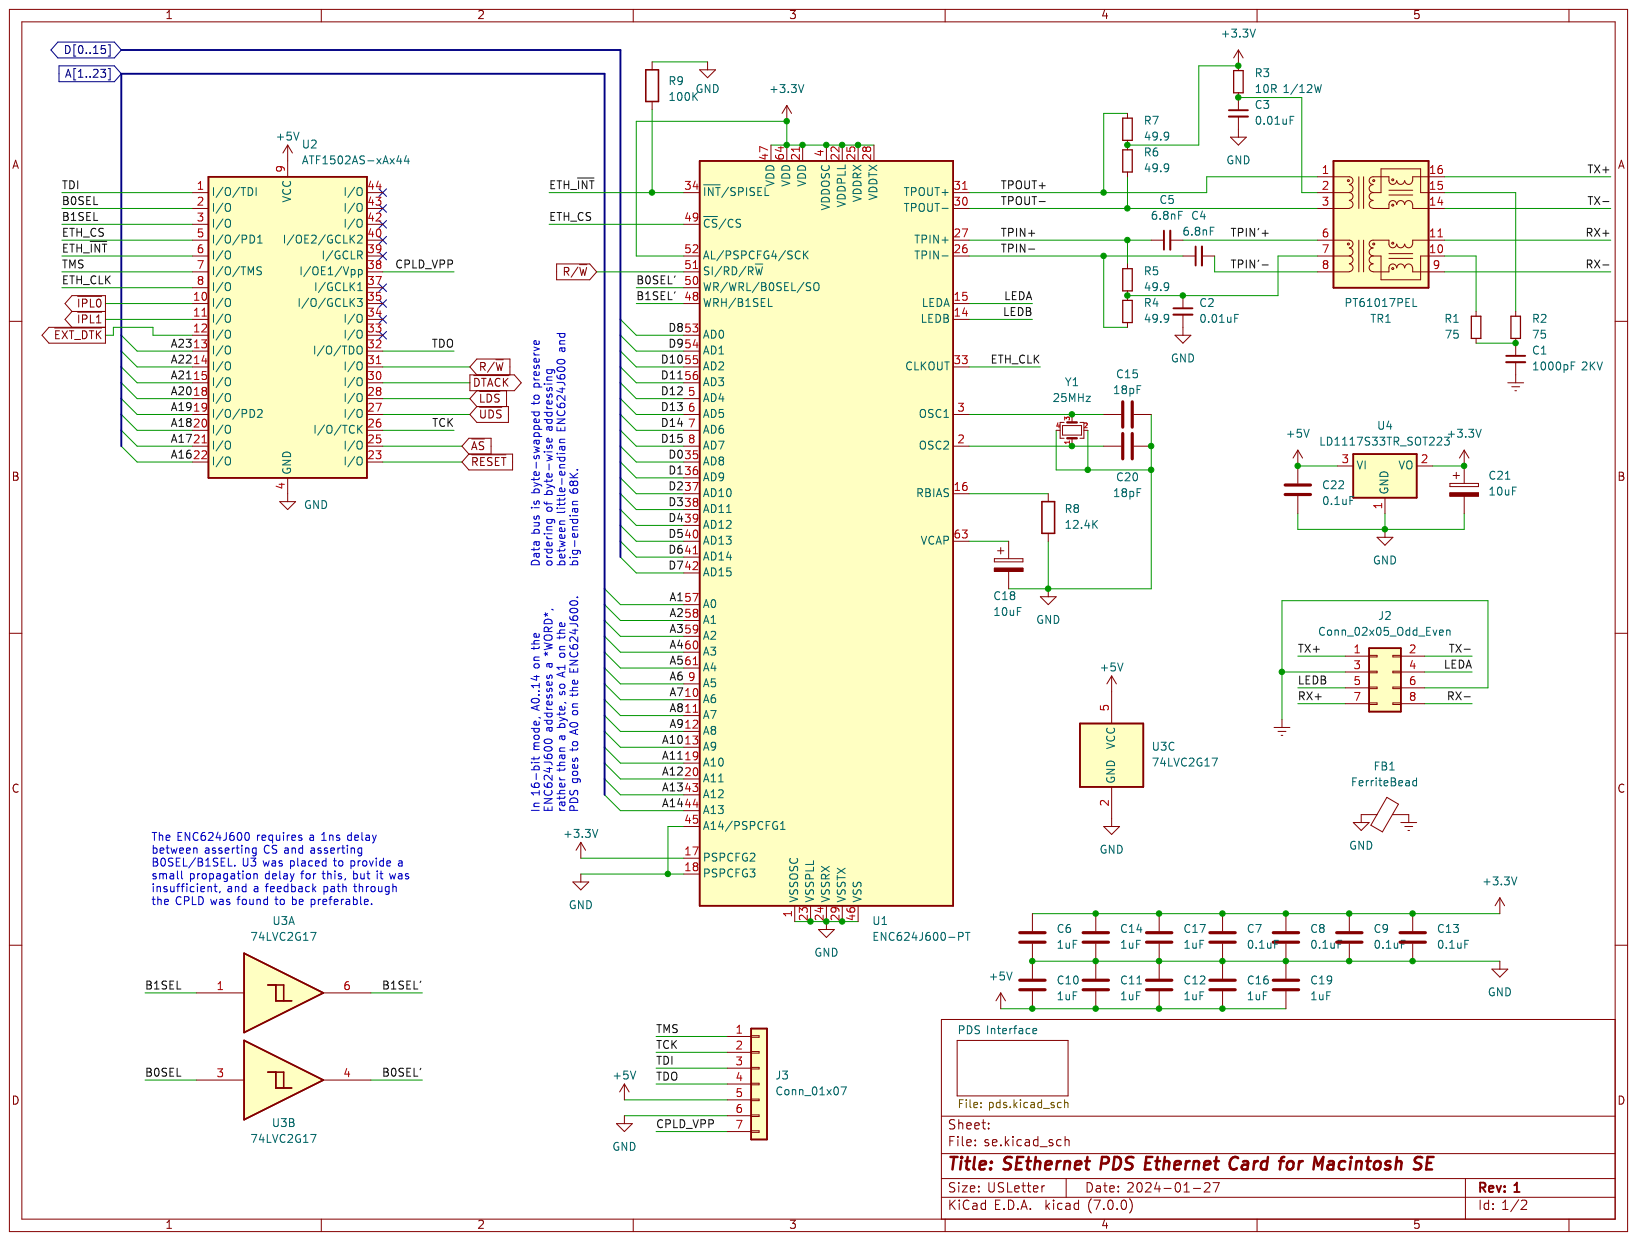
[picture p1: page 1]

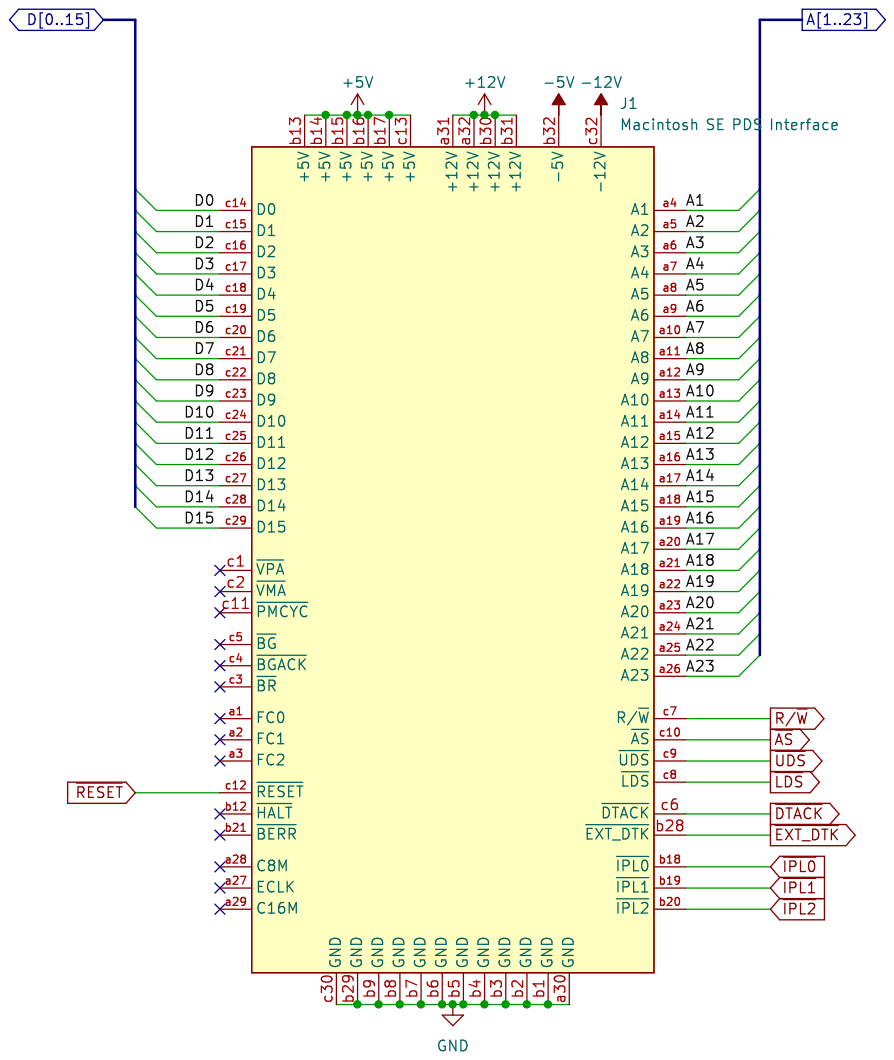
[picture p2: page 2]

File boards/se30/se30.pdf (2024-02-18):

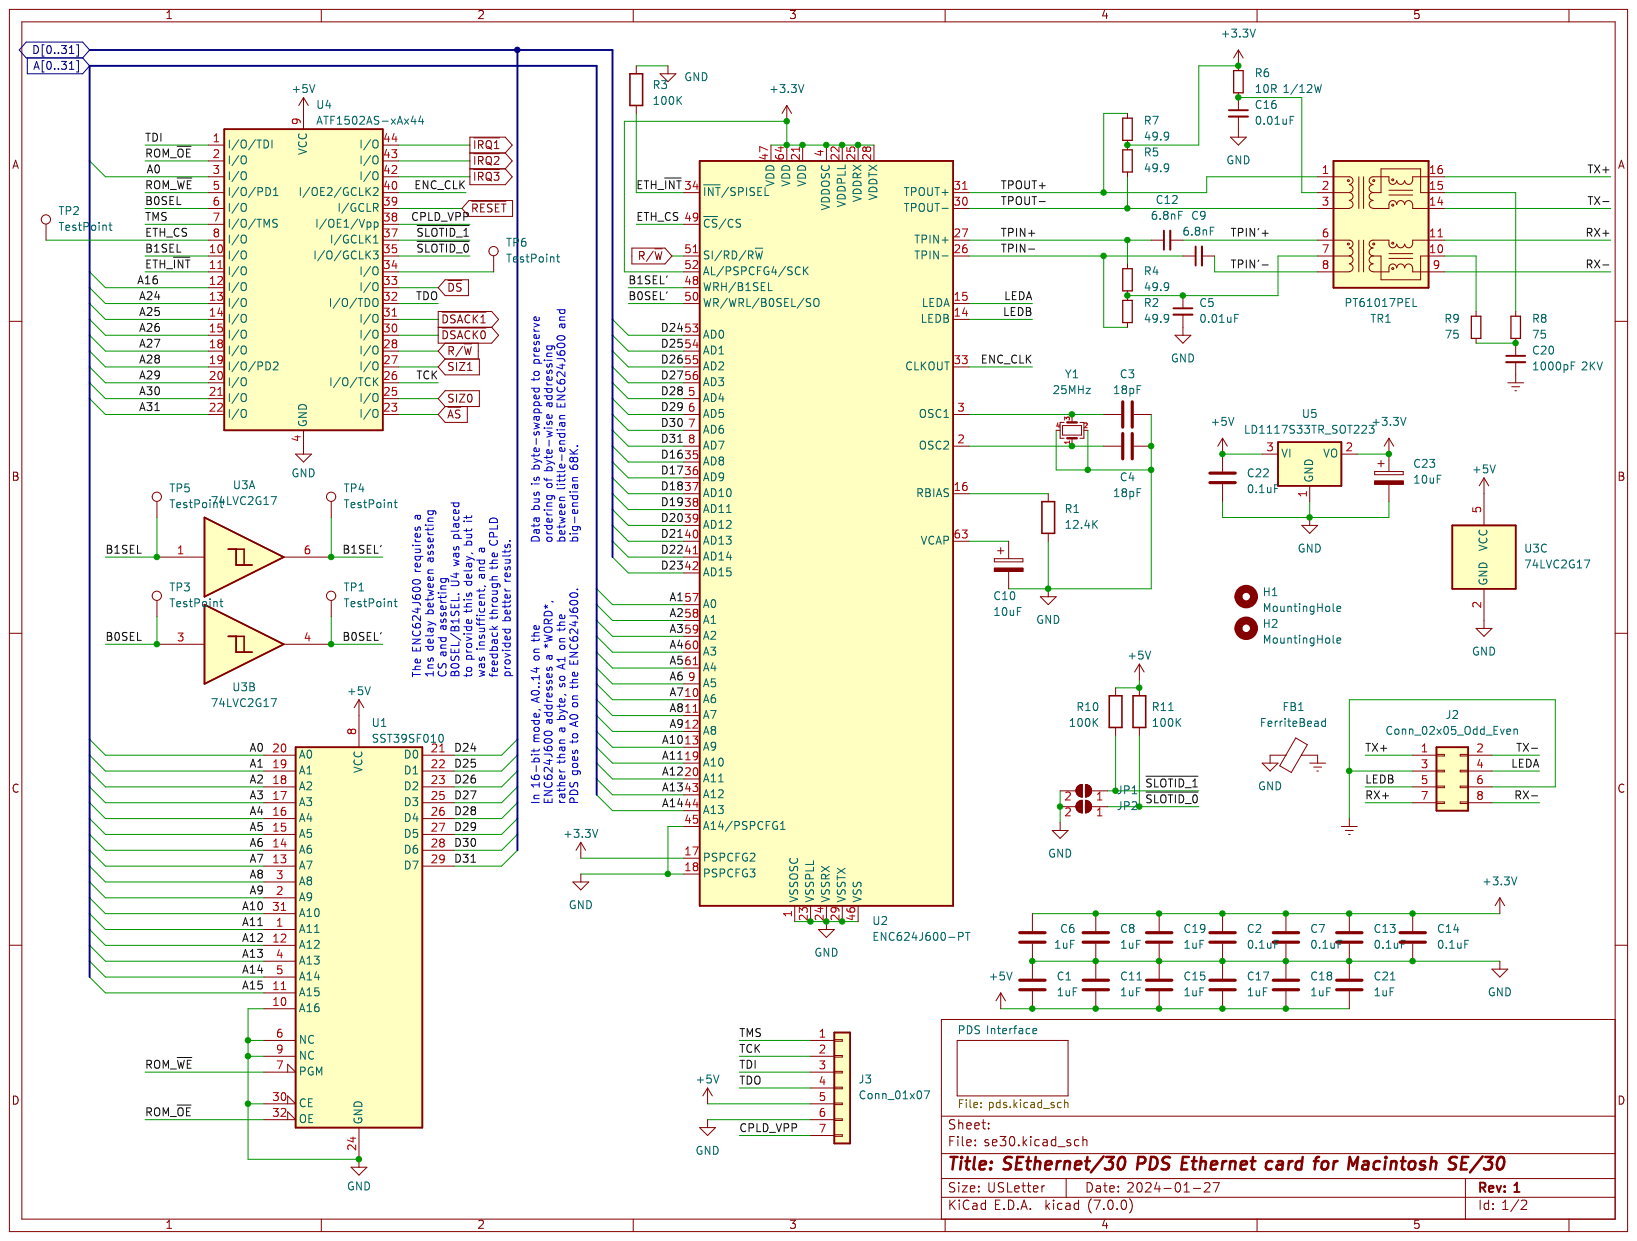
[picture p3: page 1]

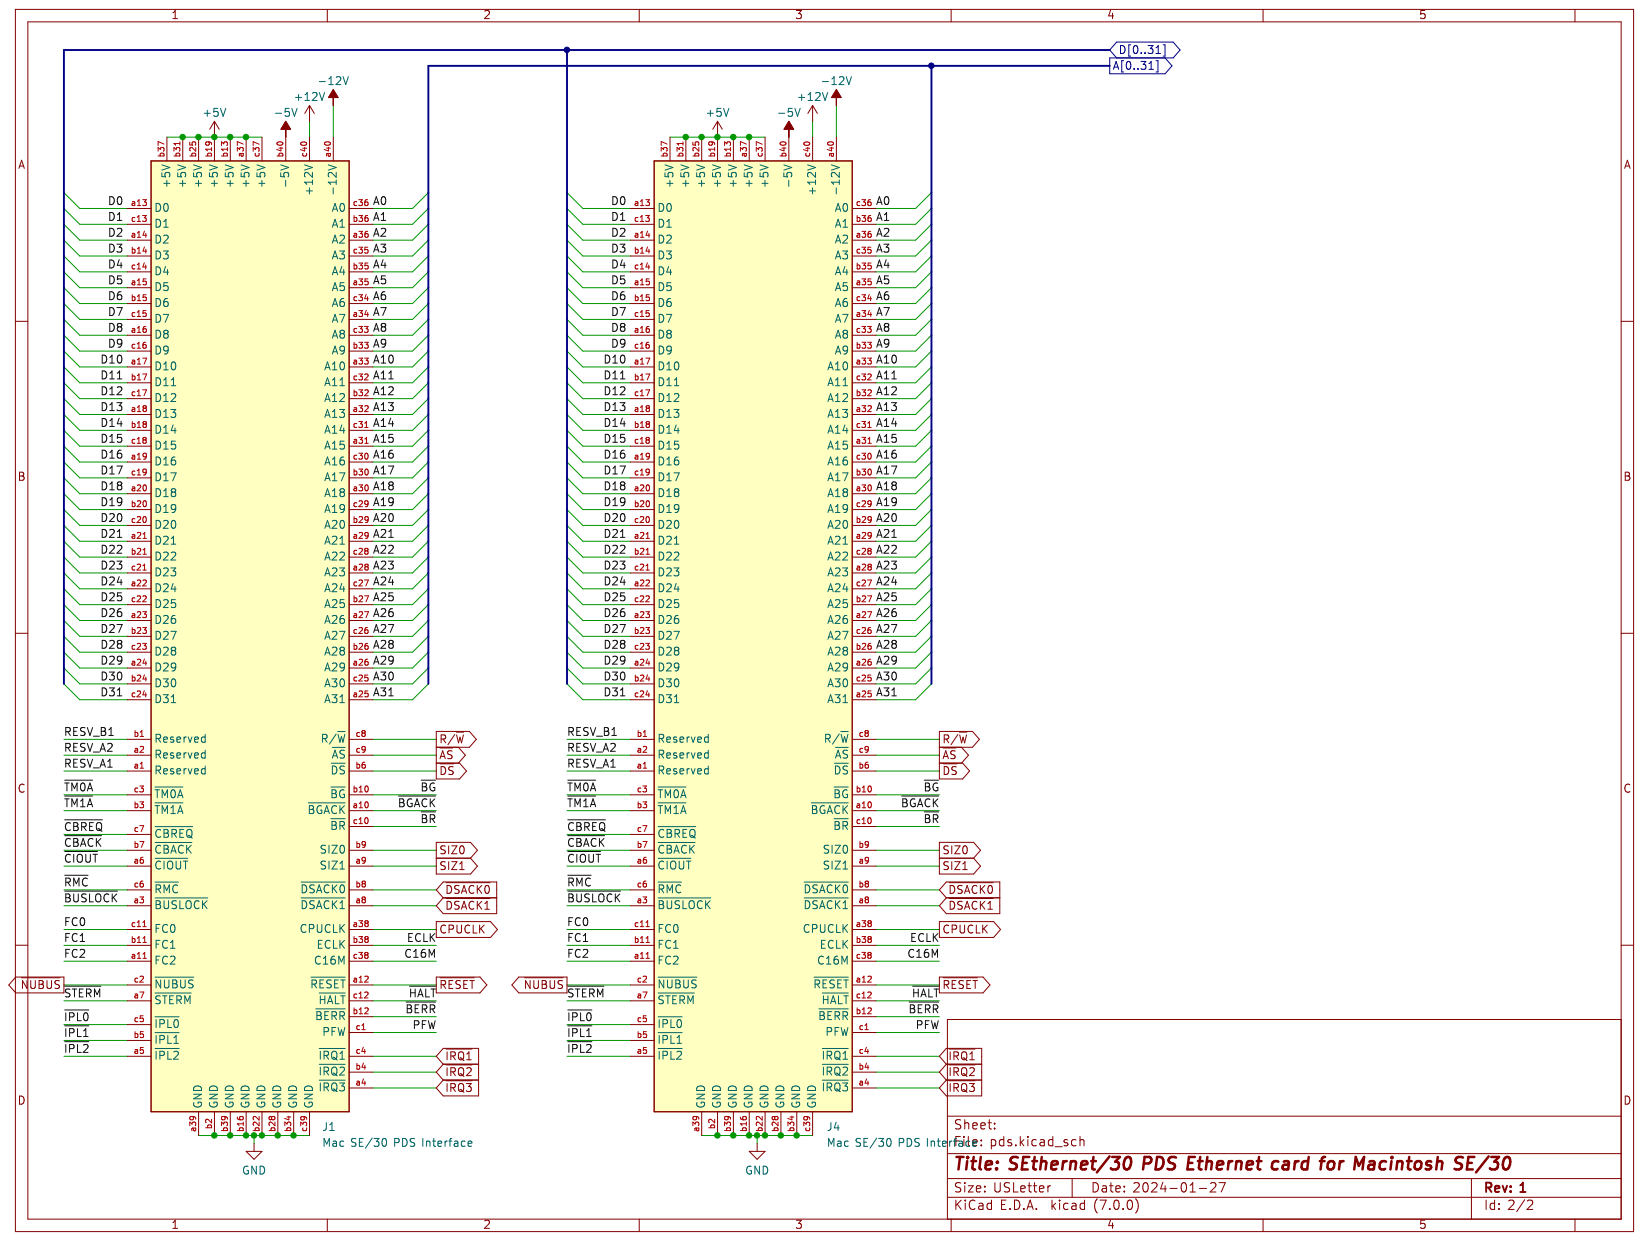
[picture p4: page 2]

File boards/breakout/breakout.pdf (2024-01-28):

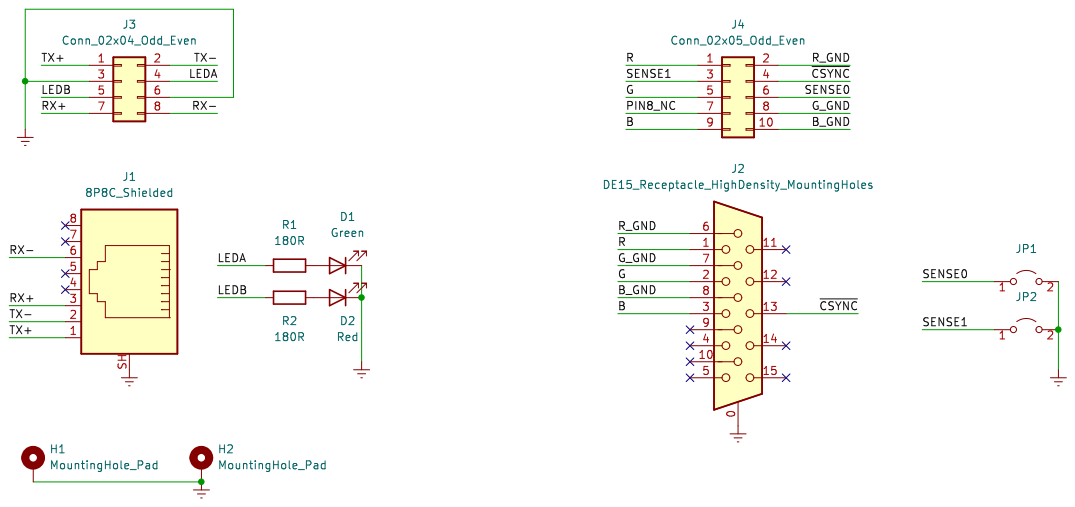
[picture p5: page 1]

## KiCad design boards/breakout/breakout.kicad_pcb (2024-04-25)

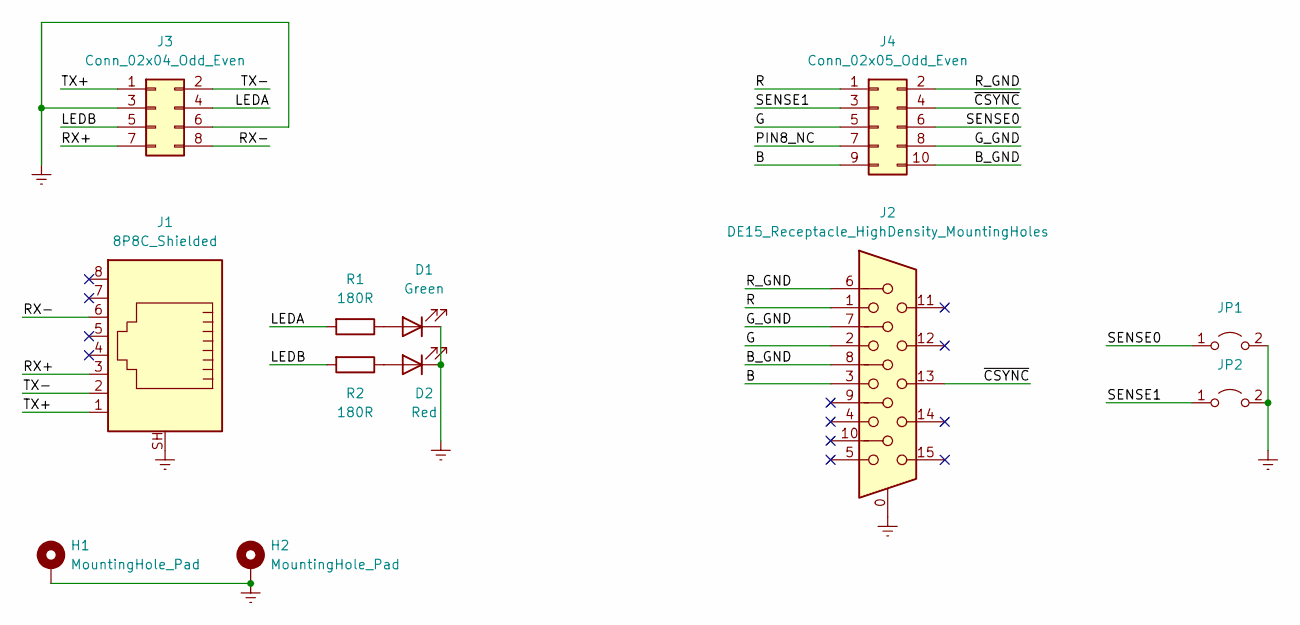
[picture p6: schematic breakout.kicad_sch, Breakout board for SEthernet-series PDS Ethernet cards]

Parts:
D1: Green; LED_D3.0mm; Digikey 151031VS06000
D2: Red; LED_D3.0mm; Digikey 151031SS06000
H1, H2: MountingHole_Pad; Wurth_9774025360R; Digikey 9774025360R
J1: 8P8C_Shielded; Kycon-GDTX-S-88_Vertical; Digikey GDTX-S-88
J2: DE15_Receptacle_HighDensity_MountingHoles; DSUB-15-HD_Female_Vertical_P2.29x1.98mm_MountingHoles; Digikey L77HDEH15SOL2RM832
J3: Conn_02x04_Odd_Even; IDC-Header_2x04_P2.54mm_Vertical; Digikey 302-S101
J4: Conn_02x05_Odd_Even; IDC-Header_2x05_P2.54mm_Vertical; Digikey 302-S101
JP1, JP2: Jumper_2_Bridged; PinHeader_1x02_P2.54mm_Vertical
R1, R2: 180R; R_Axial_DIN0204_L3.6mm_D1.6mm_P7.62mm_Horizontal; Digikey CF18JT180R

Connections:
/B: J2.3, J4.9
/B_GND: J2.8, J4.10
/G: J2.2, J4.5
/G_GND: J2.7, J4.8
/LEDA: J3.4, R1.2
/LEDB: J3.5, R2.2
/PIN8_NC: J4.7
/R: J2.1, J4.1
/RX+: J1.3, J3.7
/RX-: J1.6, J3.8
/R_GND: J2.6, J4.2
/SENSE0: J4.6, JP1.1 (A)
/SENSE1: J4.3, JP2.1 (A)
/TX+: J1.1, J3.1
/TX-: J1.2, J3.2
/~CSYNC: J2.13, J4.4
Earth: D1.1 (K), D2.1 (K), H1.1, H2.1, J1.SH, J2.0, J3.3, J3.6, JP1.2 (B), JP2.2 (B)
unnamed: D1.2 (A), R1.1
unnamed: D2.2 (A), R2.1

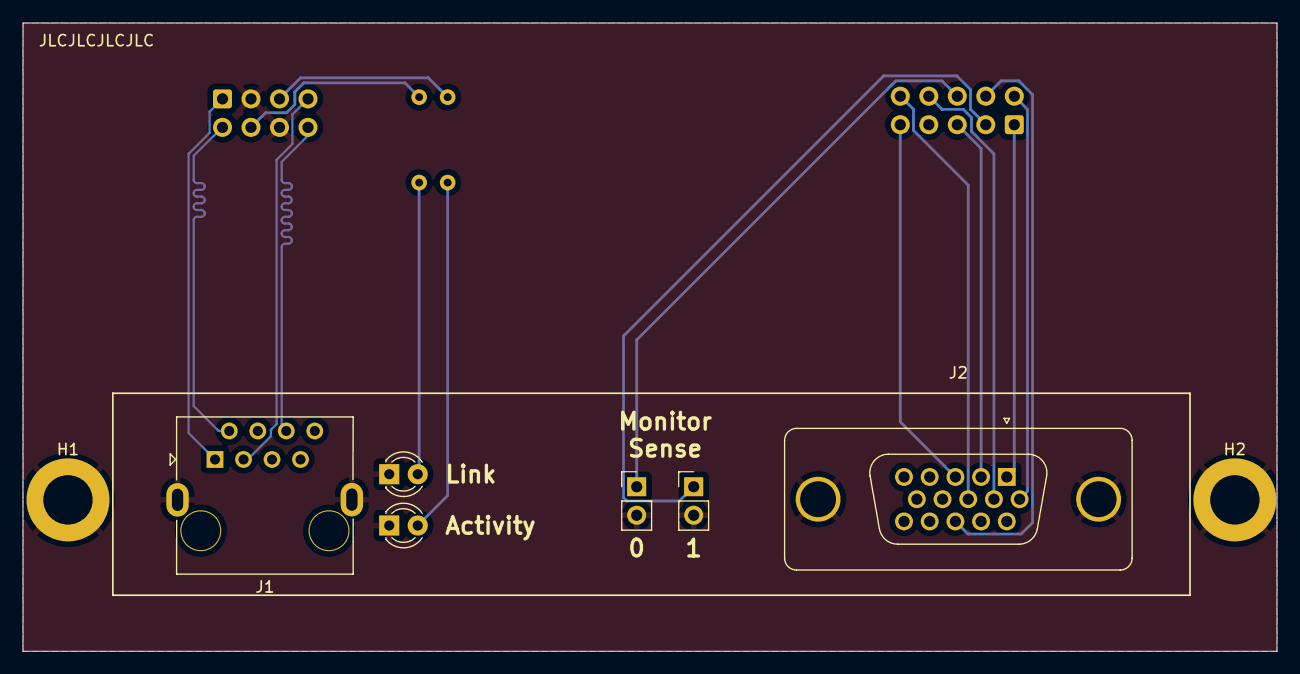
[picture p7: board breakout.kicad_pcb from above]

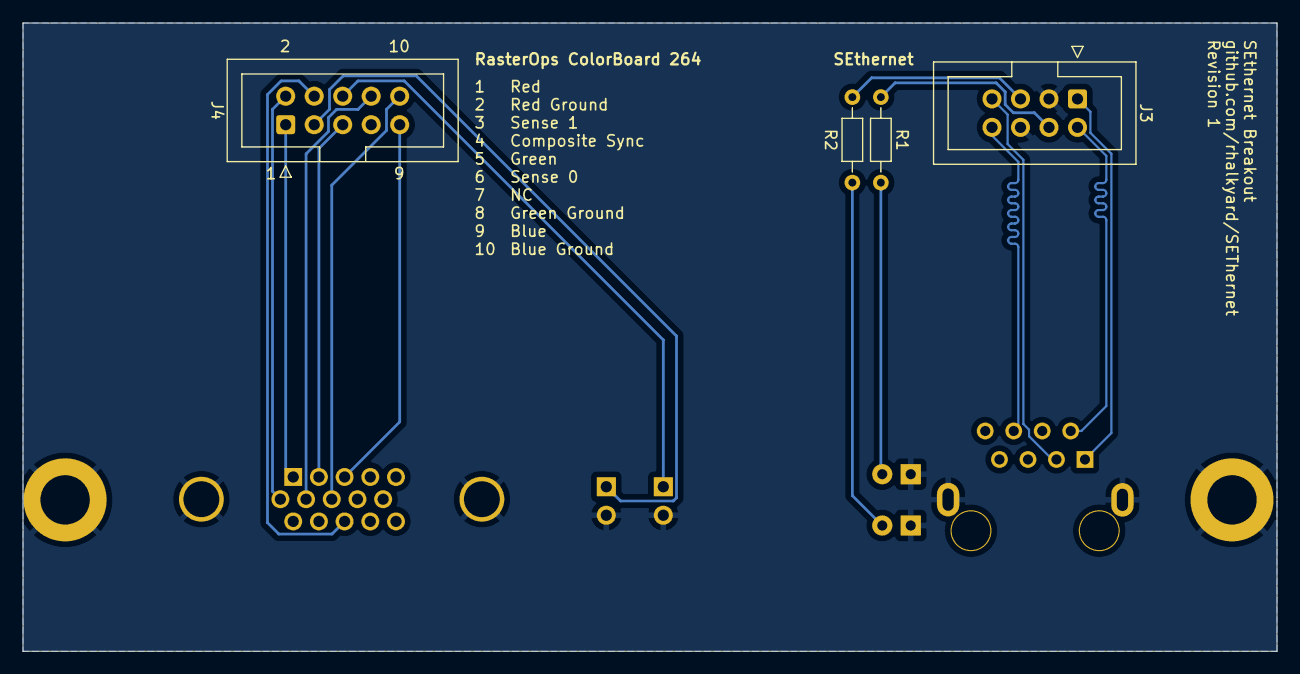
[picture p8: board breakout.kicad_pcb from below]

Board: 2 copper layers, 111.8 x 56.0 mm, 12 parts (4 on the bottom side), 18 nets.

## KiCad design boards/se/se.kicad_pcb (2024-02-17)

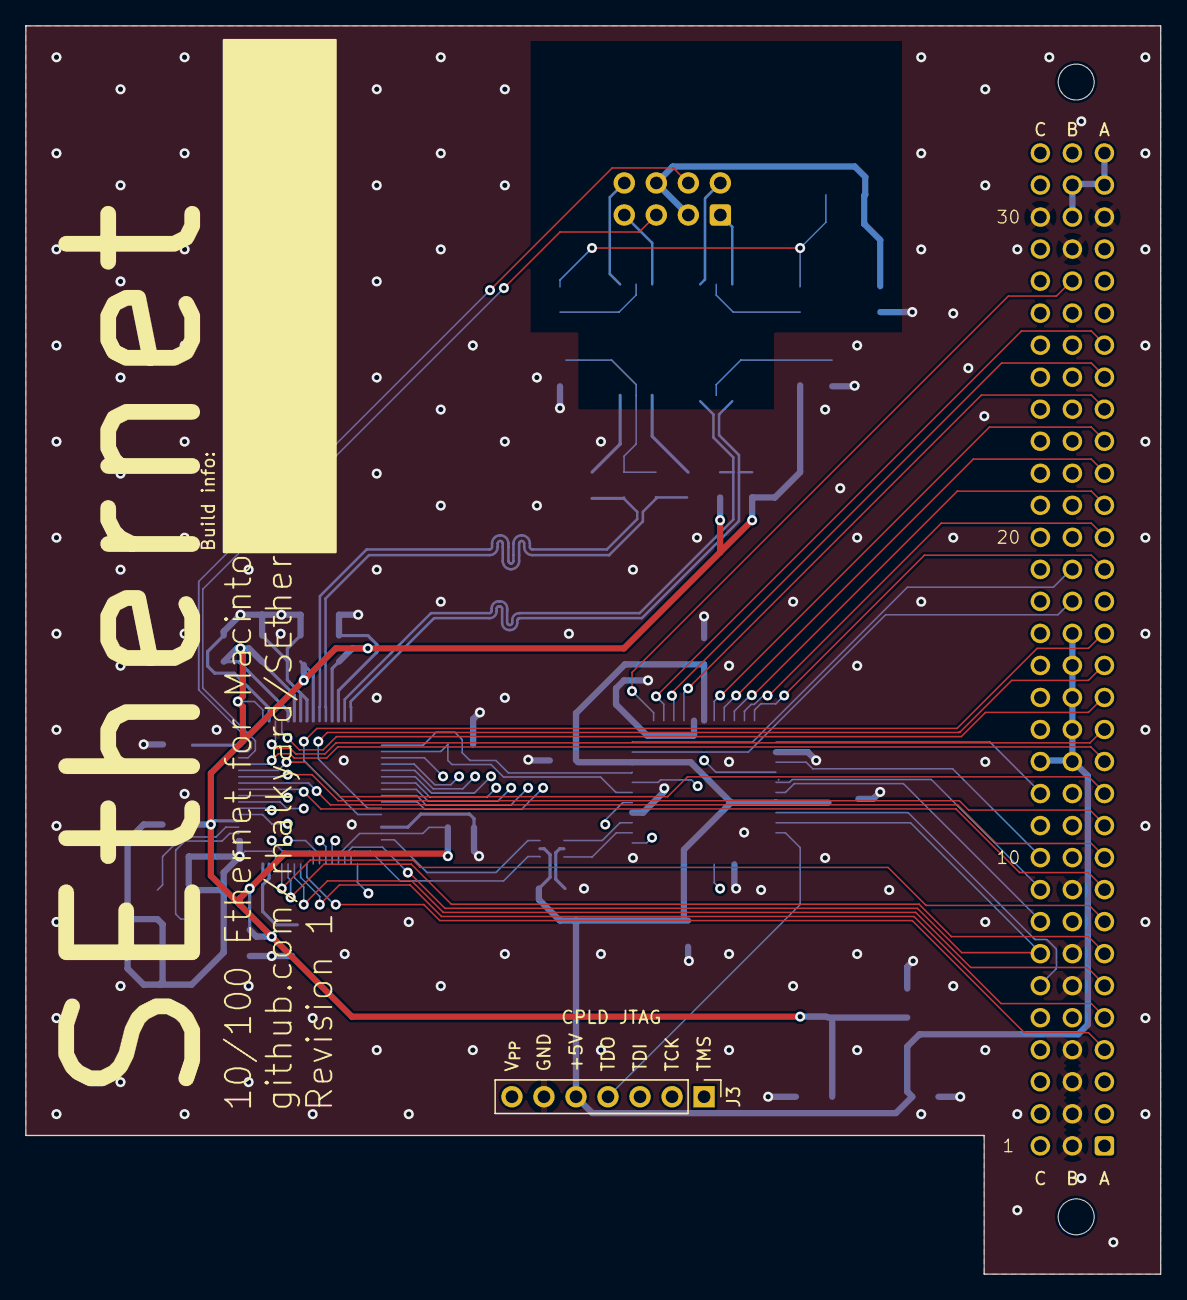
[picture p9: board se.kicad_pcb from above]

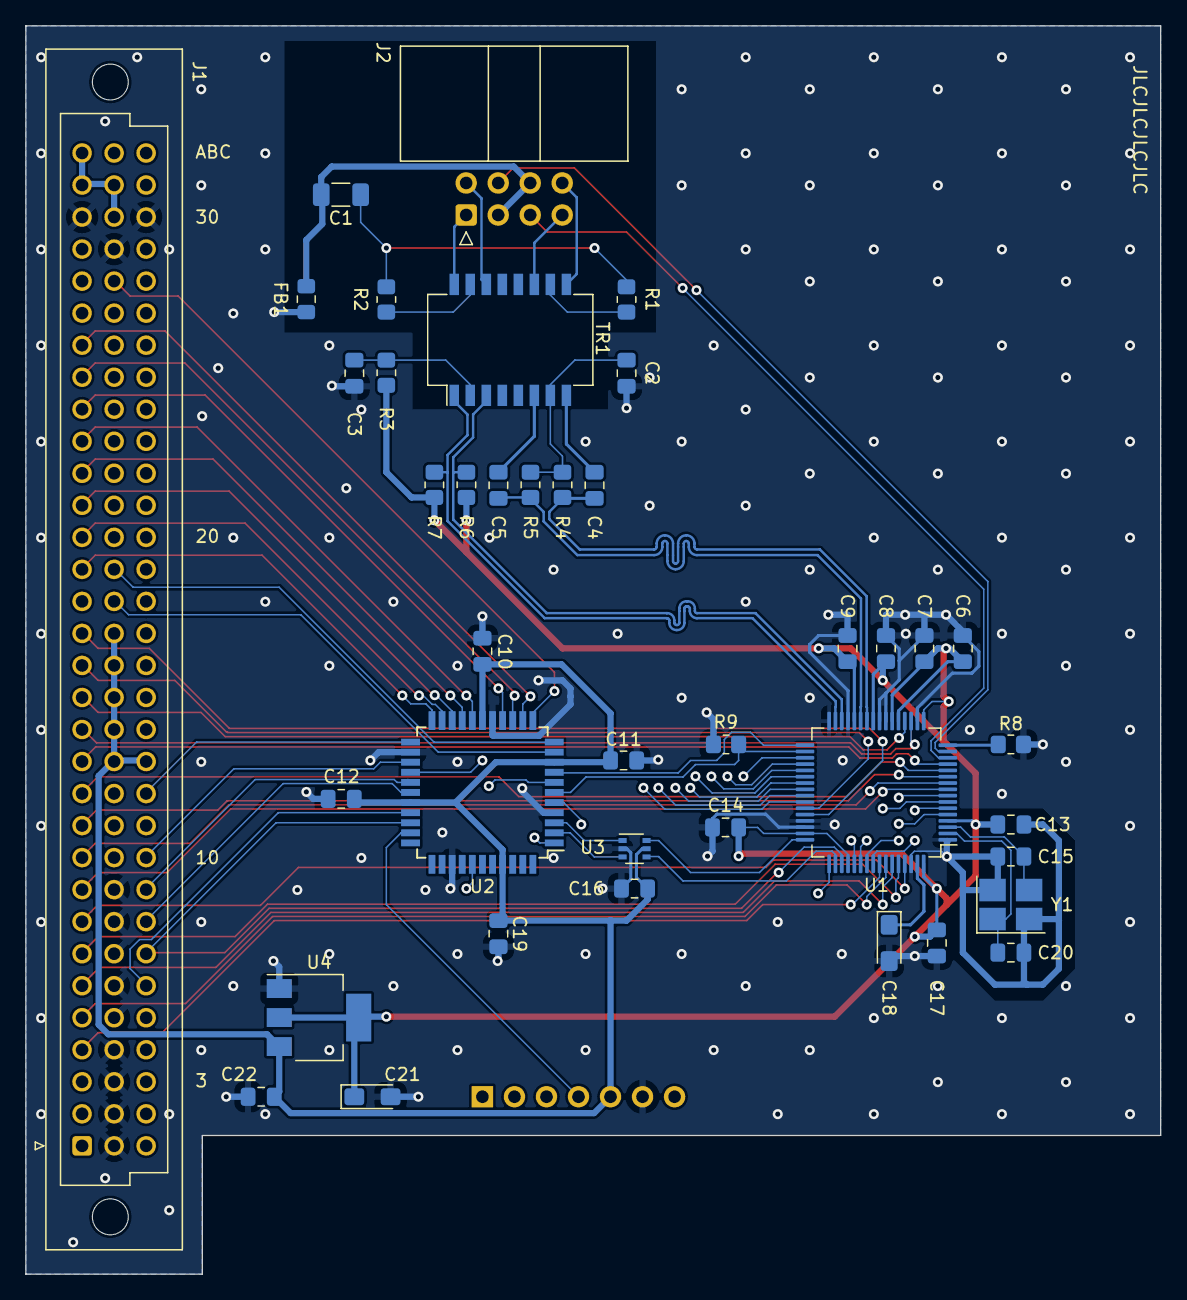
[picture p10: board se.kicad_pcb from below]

Board: 4 copper layers, 90.0 x 99.0 mm, 41 parts (40 on the bottom side), 85 nets.

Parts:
C1: 1000pF 2KV; C_1206_3216Metric_Pad1.33x1.80mm_HandSolder
C2, C3: 0.01uF; C_0805_2012Metric_Pad1.18x1.45mm_HandSolder
C4, C5: 6.8nF; C_0805_2012Metric_Pad1.18x1.45mm_HandSolder
C6, C10, C11, C12, C14, C16, C17, C19: 1uF; C_0805_2012Metric_Pad1.18x1.45mm_HandSolder
C7, C8, C9, C13, C22: 0.1uF; C_0805_2012Metric_Pad1.18x1.45mm_HandSolder
C15, C20: 18pF; C_0805_2012Metric_Pad1.18x1.45mm_HandSolder
C18, C21: 10uF; CP_EIA-3216-18_Kemet-A_Pad1.58x1.35mm_HandSolder
FB1: FerriteBead; L_0805_2012Metric_Pad1.15x1.40mm_HandSolder
J1: Macintosh SE PDS Interface; DIN41612_C_3x32_Female_Vertical_THT_Reversed
J2: Conn_02x05_Odd_Even; IDC-Header_2x04_P2.54mm_Horizontal
J3: Conn_01x07; PinHeader_1x07_P2.54mm_Vertical
R1, R2: 75; R_0805_2012Metric_Pad1.20x1.40mm_HandSolder
R3: 10R 1/12W; R_0805_2012Metric_Pad1.20x1.40mm_HandSolder
R4, R5, R6, R7: 49.9; R_0805_2012Metric_Pad1.20x1.40mm_HandSolder
R8: 12.4K; R_0805_2012Metric_Pad1.20x1.40mm_HandSolder
R9: 100K; R_0805_2012Metric_Pad1.20x1.40mm_HandSolder
TR1: PT61017PEL; Transformer_Ethernet_Bourns_PT61017PEL
U1: ENC624J600-PT; TQFP-64_10x10mm_P0.5mm
U2: ATF1502AS-xAx44; TQFP-44_10x10mm_P0.8mm
U3: 74LVC2G17; SOT-363_SC-70-6
U4: LD1117S33TR_SOT223; SOT-223-3_TabPin2
Y1: 25MHz; Crystal_SMD_3225-4Pin_3.2x2.5mm_HandSoldering

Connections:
+3.3V: C6.1, C7.1, C8.2, C9.1, C13.2, C14.1, C17.2, C21.1, R3.1, R6.1, R7.2, U1.4 (VDDOSC), U1.17 (PSPCFG2), U1.21 (VDD), U1.22 (VDDPLL), U1.25 (VDDRX), U1.28 (VDDTX), U1.47 (VDD), U1.52 (AL/PSPCFG4/SCK), U1.64 (VDD), U4.2 (VO)
+5V: C10.1, C11.1, C12.1, C16.1, C19.1, C22.1, J1.b13 (+5V), J1.b14 (+5V), J1.b15 (+5V), J1.b16 (+5V), J1.b17 (+5V), J1.c13 (+5V), J3.5, U2.9 (VCC), U2.17 (VCC), U2.29 (VCC), U2.41 (VCC), U3.5 (VCC), U4.3 (VI)
+12V: J1.a31 (+12V), J1.a32 (+12V), J1.b30 (+12V), J1.b31 (+12V)
/B0SEL: U2.2 (I/O), U3.3
/B0SEL': U1.50 (WR/WRL/B0SEL/SO), U3.4
/B1SEL: U2.3 (I/O), U3.1
/B1SEL': U1.48 (WRH/B1SEL), U3.6
/CPLD_VPP: J3.7, U2.38 (I/OE1/Vpp)
/ETH_CLK: U1.33 (CLKOUT), U2.8 (I/O)
/ETH_CS: U1.49 (~CS/CS), U2.5 (I/O/PD1)
/ETH_~INT: R9.2, U1.34 (~INT/SPISEL), U2.6 (I/O)
/LEDA: J2.4, U1.15 (LEDA)
/LEDB: J2.5, U1.14 (LEDB)
/RX+: J2.7, TR1.11 (RX+)
/RX-: J2.8, TR1.9 (RX-)
/TCK: J3.2, U2.26 (I/O/TCK)
/TDI: J3.3, U2.1 (I/O/TDI)
/TDO: J3.4, U2.32 (I/O/TDO)
/TMS: J3.1, U2.7 (I/O/TMS)
/TPIN'+: C5.2, TR1.6 (RD+)
/TPIN'-: C4.2, TR1.8 (RD-)
/TPIN+: C5.1, R5.1, U1.27 (TPIN+)
/TPIN-: C4.1, R4.2, U1.26 (TPIN-)
/TPOUT+: R7.1, TR1.1 (TD+), U1.31 (TPOUT+)
/TPOUT-: R6.2, TR1.3 (TD-), U1.30 (TPOUT-)
/TX+: J2.1, TR1.16 (TX+)
/TX-: J2.2, TR1.14 (TX-)
A1: J1.a4 (A1), U1.57 (A0)
A2: J1.a5 (A2), U1.58 (A1)
A3: J1.a6 (A3), U1.59 (A2)
A4: J1.a7 (A4), U1.60 (A3)
A5: J1.a8 (A5), U1.61 (A4)
A6: J1.a9 (A6), U1.9 (A5)
A7: J1.a10 (A7), U1.10 (A6)
A8: J1.a11 (A8), U1.11 (A7)
A9: J1.a12 (A9), U1.12 (A8)
A10: J1.a13 (A10), U1.13 (A9)
A11: J1.a14 (A11), U1.19 (A10)
A12: J1.a15 (A12), U1.20 (A11)
A13: J1.a16 (A13), U1.43 (A12)
A14: J1.a17 (A14), U1.44 (A13)
A16: J1.a19 (A16), U2.22 (I/O)
A17: J1.a20 (A17), U2.21 (I/O)
A18: J1.a21 (A18), U2.20 (I/O)
A19: J1.a22 (A19), U2.19 (I/O/PD2)
A20: J1.a23 (A20), U2.18 (I/O)
A21: J1.a24 (A21), U2.15 (I/O)
A22: J1.a25 (A22), U2.14 (I/O)
A23: J1.a26 (A23), U2.13 (I/O)
D0: J1.c14 (D0), U1.35 (AD8)
D1: J1.c15 (D1), U1.36 (AD9)
D2: J1.c16 (D2), U1.37 (AD10)
D3: J1.c17 (D3), U1.38 (AD11)
D4: J1.c18 (D4), U1.39 (AD12)
D5: J1.c19 (D5), U1.40 (AD13)
D6: J1.c20 (D6), U1.41 (AD14)
D7: J1.c21 (D7), U1.42 (AD15)
D8: J1.c22 (D8), U1.53 (AD0)
D9: J1.c23 (D9), U1.54 (AD1)
D10: J1.c24 (D10), U1.55 (AD2)
D11: J1.c25 (D11), U1.56 (AD3)
D12: J1.c26 (D12), U1.5 (AD4)
D13: J1.c27 (D13), U1.6 (AD5)
D14: J1.c28 (D14), U1.7 (AD6)
D15: J1.c29 (D15), U1.8 (AD7)
Earth: C1.2, FB1.2, J2.3, J2.6
GND: C2.2, C3.2, C6.2, C7.2, C8.1, C9.2, C10.2, C11.2, C12.2, C13.1, C14.2, C15.2, C16.2, C17.1, C18.2, C19.2, C20.2, C21.2, C22.2, FB1.1, J1.a30 (GND), J1.b1 (GND), J1.b2 (GND), J1.b3 (GND), J1.b4 (GND), J1.b5 (GND), J1.b6 (GND), J1.b7 (GND), J1.b8 (GND), J1.b9 (GND), J1.b29 (GND), J1.c30 (GND), J3.6, R8.2, R9.1, U1.1 (VSSOSC), U1.18 (PSPCFG3), U1.23 (VSSPLL), U1.24 (VSSRX), U1.29 (VSSTX), U1.32 (VSSTX), U1.45 (A14/PSPCFG1), U1.46 (VSS), U1.62 (VSS), U2.4 (GND), U2.16 (GND), U2.24 (GND), U2.36 (GND), U3.2 (GND), U4.1 (GND), Y1.2, Y1.4
unnamed: C1.1, R1.2, R2.2
unnamed: C2.1, R4.1, R5.2, TR1.7 (C_RD)
unnamed: R1.1, TR1.10 (C_RX)
unnamed: C3.1, R3.2, TR1.2 (C_TD)
unnamed: R2.1, TR1.15 (C_TX)
unnamed: C15.1, U1.3 (OSC1), Y1.3
unnamed: C20.1, U1.2 (OSC2), Y1.1
unnamed: R8.1, U1.16 (RBIAS)
unnamed: C18.1, U1.63 (VCAP)
R/~W: J1.c7 (R/~W), U1.51 (SI/RD/R~W), U2.31 (I/O)
~AS: J1.c10 (~AS), U2.25 (I/O)
~DTACK: J1.c6 (~DTACK), U2.30 (I/O)
~EXT_DTK: J1.b28 (~EXT_DTK), U2.12 (I/O)
~IPL0: J1.b18 (~IPL0), U2.10 (I/O)
~IPL1: J1.b19 (~IPL1), U2.11 (I/O)
~LDS: J1.c8 (~LDS), U2.28 (I/O)
~RESET: J1.c12 (~RESET), U2.23 (I/O)
~UDS: J1.c9 (~UDS), U2.27 (I/O)

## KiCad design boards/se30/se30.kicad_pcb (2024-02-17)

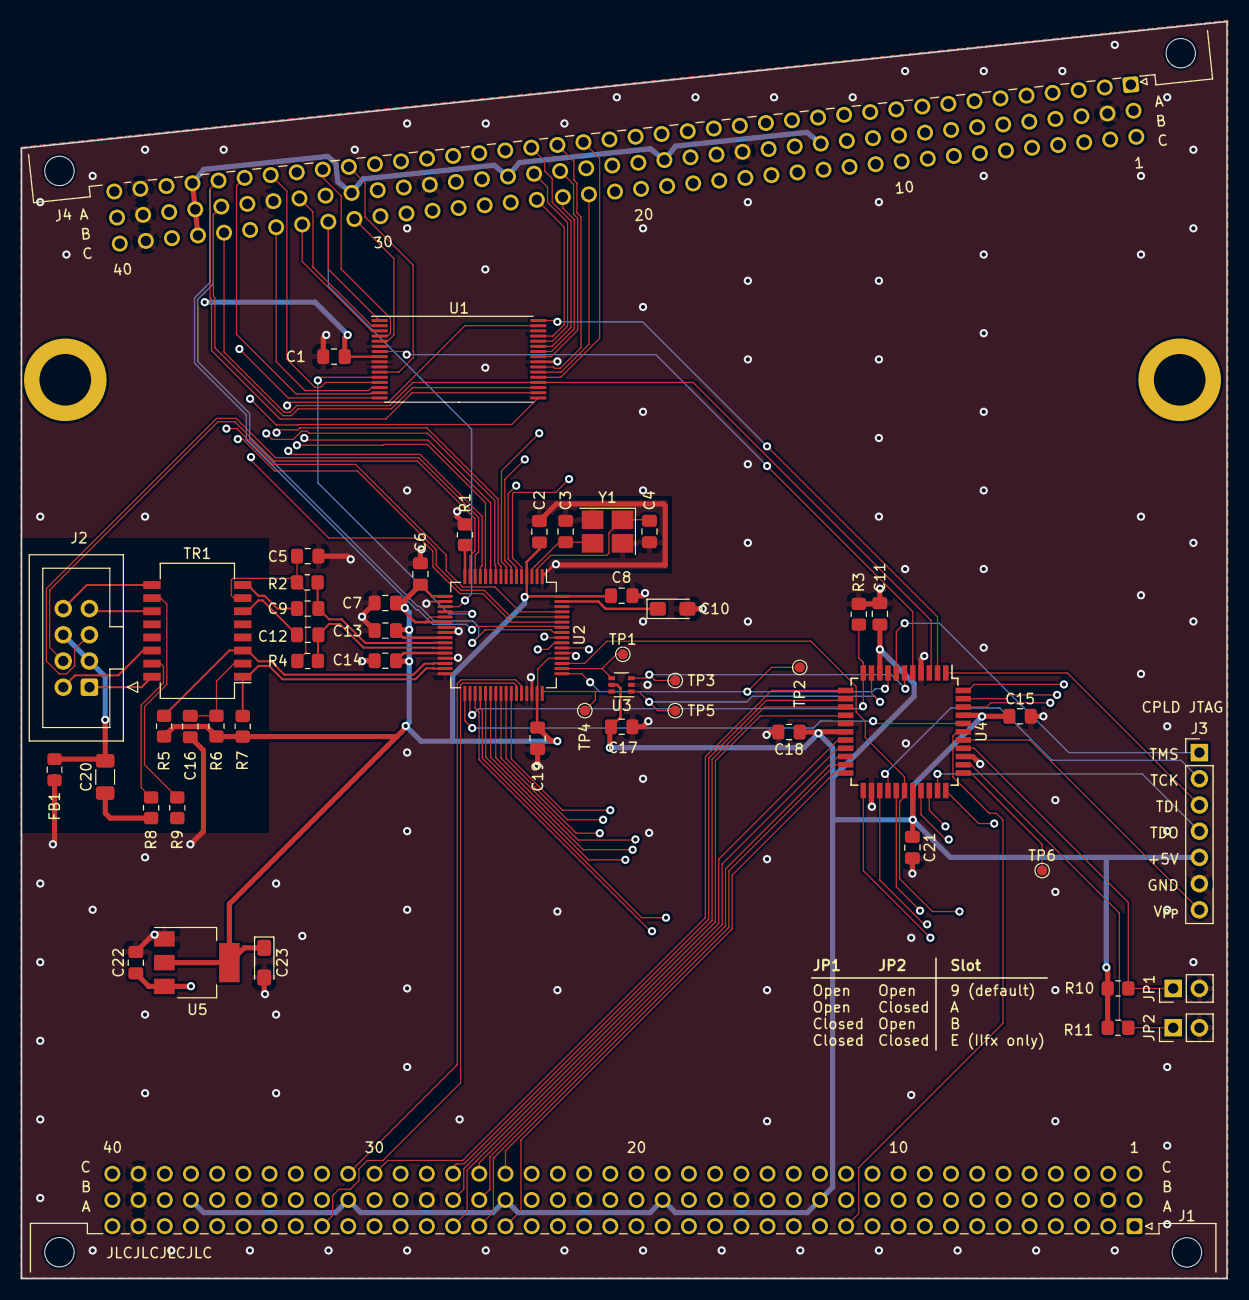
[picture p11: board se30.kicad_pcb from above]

Board: 4 copper layers, 116.8 x 121.8 mm, 56 parts (0 on the bottom side), 147 nets.

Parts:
C1, C6, C8, C11, C15, C17, C18, C19, C21: 1uF; C_0805_2012Metric_Pad1.18x1.45mm_HandSolder
C2, C7, C13, C14, C22: 0.1uF; C_0805_2012Metric_Pad1.18x1.45mm_HandSolder
C3, C4: 18pF; C_0805_2012Metric_Pad1.18x1.45mm_HandSolder
C5, C16: 0.01uF; C_0805_2012Metric_Pad1.18x1.45mm_HandSolder
C9, C12: 6.8nF; C_0805_2012Metric_Pad1.18x1.45mm_HandSolder
C10, C23: 10uF; CP_EIA-3216-18_Kemet-A_Pad1.58x1.35mm_HandSolder
C20: 1000pF 2KV; C_1206_3216Metric_Pad1.33x1.80mm_HandSolder
FB1: FerriteBead; L_0805_2012Metric_Pad1.15x1.40mm_HandSolder
H1, H2: MountingHole; MountingHole_5mm
J1: Mac SE/30 PDS Interface; DIN41612_C_3x40_Male_Horizontal_THT
J2: Conn_02x05_Odd_Even; IDC-Header_2x04_P2.54mm_Vertical
J3: Conn_01x07; PinHeader_1x07_P2.54mm_Vertical
J4: Mac SE/30 PDS Interface; DIN41612_C_3x40_Female_Horizontal_THT
JP1, JP2: SolderJumper_2_Open; PinHeader_1x02_P2.54mm_Vertical
R1: 12.4K; R_0805_2012Metric_Pad1.20x1.40mm_HandSolder
R2, R4, R5, R7: 49.9; R_0805_2012Metric_Pad1.20x1.40mm_HandSolder
R3: 100K; R_0805_2012Metric_Pad1.20x1.40mm_HandSolder
R6: 10R 1/12W; R_0805_2012Metric_Pad1.20x1.40mm_HandSolder
R8, R9: 75; R_0805_2012Metric_Pad1.20x1.40mm_HandSolder
R10, R11: 10K; R_0805_2012Metric_Pad1.20x1.40mm_HandSolder
TP1, TP2, TP3, TP4, TP5, TP6: TestPoint; TestPoint_Pad_D1.0mm
TR1: PT61017PEL; Transformer_Ethernet_Bourns_PT61017PEL
U1: SST39SF010; TSOP-I-32_14.4x8mm_P0.5mm
U2: ENC624J600-PT; TQFP-64_10x10mm_P0.5mm
U3: 74LVC2G17; SOT-363_SC-70-6
U4: ATF1502AS-xAx44; TQFP-44_10x10mm_P0.8mm
U5: LD1117S33TR_SOT223; SOT-223-3_TabPin2
Y1: 25MHz; Crystal_SMD_3225-4Pin_3.2x2.5mm_HandSoldering

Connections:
+3.3V: C2.2, C6.2, C7.1, C8.1, C13.2, C14.1, C19.1, C23.1, R5.1, R6.1, R7.2, U2.4 (VDDOSC), U2.17 (PSPCFG2), U2.21 (VDD), U2.22 (VDDPLL), U2.25 (VDDRX), U2.28 (VDDTX), U2.47 (VDD), U2.52 (AL/PSPCFG4/SCK), U2.64 (VDD), U5.2 (VO)
+5V: C1.1, C11.1, C15.1, C17.1, C18.1, C21.1, C22.1, J1.a37 (+5V), J1.b13 (+5V), J1.b19 (+5V), J1.b25 (+5V), J1.b31 (+5V), J1.b37 (+5V), J1.c37 (+5V), J3.5, J4.a37 (+5V), J4.b13 (+5V), J4.b19 (+5V), J4.b25 (+5V), J4.b31 (+5V), J4.b37 (+5V), J4.c37 (+5V), R10.1, R11.1, U1.8 (VCC), U3.5 (VCC), U4.9 (VCC), U4.17 (VCC), U4.29 (VCC), U4.41 (VCC), U5.3 (VI)
+12V: J1.c40 (+12V), J4.c40 (+12V)
-5V: J1.b40 (-5V), J4.b40 (-5V)
-12V: J1.a40 (-12V), J4.a40 (-12V)
/B0SEL: TP3.1, U3.3, U4.6 (I/O)
/B0SEL': TP1.1, U2.50 (WR/WRL/B0SEL/SO), U3.4
/B1SEL: TP5.1, U3.1, U4.10 (I/O)
/B1SEL': TP4.1, U2.48 (WRH/B1SEL), U3.6
/CPLD_VPP: J3.7, U4.38 (I/OE1/Vpp)
/ENC_CLK: U2.33 (CLKOUT), U4.40 (I/OE2/GCLK2)
/ETH_CS: TP2.1, U2.49 (~CS/CS), U4.8 (I/O)
/ETH_~INT: R3.2, U2.34 (~INT/SPISEL), U4.11 (I/O)
/LEDA: J2.4, U2.15 (LEDA)
/LEDB: J2.5, U2.14 (LEDB)
/PDS Interface/C16M: J1.c38 (C16M), J4.c38 (C16M)
/PDS Interface/ECLK: J1.b38 (ECLK), J4.b38 (ECLK)
/PDS Interface/FC0: J1.c11 (FC0), J4.c11 (FC0)
/PDS Interface/FC1: J1.b11 (FC1), J4.b11 (FC1)
/PDS Interface/FC2: J1.a11 (FC2), J4.a11 (FC2)
/PDS Interface/PFW: J1.c1 (PFW), J4.c1 (PFW)
/PDS Interface/RESV_A1: J1.a1 (Reserved), J4.a1 (Reserved)
/PDS Interface/RESV_A2: J1.a2 (Reserved), J4.a2 (Reserved)
/PDS Interface/RESV_B1: J1.b1 (Reserved), J4.b1 (Reserved)
/PDS Interface/~BERR: J1.b12 (~BERR), J4.b12 (~BERR)
/PDS Interface/~BGACK: J1.a10 (~BGACK), J4.a10 (~BGACK)
/PDS Interface/~BG: J1.b10 (~BG), J4.b10 (~BG)
/PDS Interface/~BR: J1.c10 (~BR), J4.c10 (~BR)
/PDS Interface/~BUSLOCK: J1.a3 (~BUSLOCK), J4.a3 (~BUSLOCK)
/PDS Interface/~CBACK: J1.b7 (~CBACK), J4.b7 (~CBACK)
/PDS Interface/~CBREQ: J1.c7 (~CBREQ), J4.c7 (~CBREQ)
/PDS Interface/~CIOUT: J1.a6 (~CIOUT), J4.a6 (~CIOUT)
/PDS Interface/~HALT: J1.c12 (~HALT), J4.c12 (~HALT)
/PDS Interface/~IPL0: J1.c5 (~IPL0), J4.c5 (~IPL0)
/PDS Interface/~IPL1: J1.b5 (~IPL1), J4.b5 (~IPL1)
/PDS Interface/~IPL2: J1.a5 (~IPL2), J4.a5 (~IPL2)
/PDS Interface/~RMC: J1.c6 (~RMC), J4.c6 (~RMC)
/PDS Interface/~STERM: J1.a7 (~STERM), J4.a7 (~STERM)
/PDS Interface/~TM0A: J1.c3 (~TM0A), J4.c3 (~TM0A)
/PDS Interface/~TM1A: J1.b3 (~TM1A), J4.b3 (~TM1A)
/ROM_~OE: U1.32 (OE), U4.2 (I/O)
/ROM_~WE: U1.7 (PGM), U4.5 (I/O/PD1)
/RX+: J2.7, TR1.11 (RX+)
/RX-: J2.8, TR1.9 (RX-)
/TCK: J3.2, U4.26 (I/O/TCK)
/TDI: J3.3, U4.1 (I/O/TDI)
/TDO: J3.4, U4.32 (I/O/TDO)
/TMS: J3.1, U4.7 (I/O/TMS)
/TPIN'+: C12.2, TR1.6 (RD+)
/TPIN'-: C9.2, TR1.8 (RD-)
/TPIN+: C12.1, R4.1, U2.27 (TPIN+)
/TPIN-: C9.1, R2.2, U2.26 (TPIN-)
/TPOUT+: R7.1, TR1.1 (TD+), U2.31 (TPOUT+)
/TPOUT-: R5.2, TR1.3 (TD-), U2.30 (TPOUT-)
/TX+: J2.1, TR1.16 (TX+)
/TX-: J2.2, TR1.14 (TX-)
/~SLOTID_0: JP2.1 (A), R11.2, U4.35 (I/O/GCLK3)
/~SLOTID_1: JP1.1 (A), R10.2, U4.37 (I/GCLK1)
A0: J1.c36 (A0), J4.c36 (A0), U1.20 (A0), U4.3 (I/O)
A1: J1.b36 (A1), J4.b36 (A1), U1.19 (A1), U2.57 (A0)
A2: J1.a36 (A2), J4.a36 (A2), U1.18 (A2), U2.58 (A1)
A3: J1.c35 (A3), J4.c35 (A3), U1.17 (A3), U2.59 (A2)
A4: J1.b35 (A4), J4.b35 (A4), U1.16 (A4), U2.60 (A3)
A5: J1.a35 (A5), J4.a35 (A5), U1.15 (A5), U2.61 (A4)
A6: J1.c34 (A6), J4.c34 (A6), U1.14 (A6), U2.9 (A5)
A7: J1.a34 (A7), J4.a34 (A7), U1.13 (A7), U2.10 (A6)
A8: J1.c33 (A8), J4.c33 (A8), U1.3 (A8), U2.11 (A7)
A9: J1.b33 (A9), J4.b33 (A9), U1.2 (A9), U2.12 (A8)
A10: J1.a33 (A10), J4.a33 (A10), U1.31 (A10), U2.13 (A9)
A11: J1.c32 (A11), J4.c32 (A11), U1.1 (A11), U2.19 (A10)
A12: J1.b32 (A12), J4.b32 (A12), U1.12 (A12), U2.20 (A11)
A13: J1.a32 (A13), J4.a32 (A13), U1.4 (A13), U2.43 (A12)
A14: J1.c31 (A14), J4.c31 (A14), U1.5 (A14), U2.44 (A13)
A15: J1.a31 (A15), J4.a31 (A15), U1.11 (A15)
A16: J1.c30 (A16), J4.c30 (A16), U4.12 (I/O)
A17: J1.b30 (A17), J4.b30 (A17)
A18: J1.a30 (A18), J4.a30 (A18)
A19: J1.c29 (A19), J4.c29 (A19)
A20: J1.b29 (A20), J4.b29 (A20)
A21: J1.a29 (A21), J4.a29 (A21)
A22: J1.c28 (A22), J4.c28 (A22)
A23: J1.a28 (A23), J4.a28 (A23)
A24: J1.c27 (A24), J4.c27 (A24), U4.13 (I/O)
A25: J1.b27 (A25), J4.b27 (A25), U4.14 (I/O)
A26: J1.a27 (A26), J4.a27 (A26), U4.15 (I/O)
A27: J1.c26 (A27), J4.c26 (A27), U4.18 (I/O)
A28: J1.b26 (A28), J4.b26 (A28), U4.19 (I/O/PD2)
A29: J1.a26 (A29), J4.a26 (A29), U4.20 (I/O)
A30: J1.c25 (A30), J4.c25 (A30), U4.21 (I/O)
A31: J1.a25 (A31), J4.a25 (A31), U4.22 (I/O)
CPUCLK: J1.a38 (CPUCLK), J4.a38 (CPUCLK)
D0: J1.a13 (D0), J4.a13 (D0)
D1: J1.c13 (D1), J4.c13 (D1)
D2: J1.a14 (D2), J4.a14 (D2)
D3: J1.b14 (D3), J4.b14 (D3)
D4: J1.c14 (D4), J4.c14 (D4)
D5: J1.a15 (D5), J4.a15 (D5)
D6: J1.b15 (D6), J4.b15 (D6)
D7: J1.c15 (D7), J4.c15 (D7)
D8: J1.a16 (D8), J4.a16 (D8)
D9: J1.c16 (D9), J4.c16 (D9)
D10: J1.a17 (D10), J4.a17 (D10)
D11: J1.b17 (D11), J4.b17 (D11)
D12: J1.c17 (D12), J4.c17 (D12)
D13: J1.a18 (D13), J4.a18 (D13)
D14: J1.b18 (D14), J4.b18 (D14)
D15: J1.c18 (D15), J4.c18 (D15)
D16: J1.a19 (D16), J4.a19 (D16), U2.35 (AD8)
D17: J1.c19 (D17), J4.c19 (D17), U2.36 (AD9)
D18: J1.a20 (D18), J4.a20 (D18), U2.37 (AD10)
D19: J1.b20 (D19), J4.b20 (D19), U2.38 (AD11)
D20: J1.c20 (D20), J4.c20 (D20), U2.39 (AD12)
D21: J1.a21 (D21), J4.a21 (D21), U2.40 (AD13)
D22: J1.b21 (D22), J4.b21 (D22), U2.41 (AD14)
D23: J1.c21 (D23), J4.c21 (D23), U2.42 (AD15)
D24: J1.a22 (D24), J4.a22 (D24), U1.21 (D0), U2.53 (AD0)
D25: J1.c22 (D25), J4.c22 (D25), U1.22 (D1), U2.54 (AD1)
D26: J1.a23 (D26), J4.a23 (D26), U1.23 (D2), U2.55 (AD2)
D27: J1.b23 (D27), J4.b23 (D27), U1.25 (D3), U2.56 (AD3)
D28: J1.c23 (D28), J4.c23 (D28), U1.26 (D4), U2.5 (AD4)
D29: J1.a24 (D29), J4.a24 (D29), U1.27 (D5), U2.6 (AD5)
D30: J1.b24 (D30), J4.b24 (D30), U1.28 (D6), U2.7 (AD6)
D31: J1.c24 (D31), J4.c24 (D31), U1.29 (D7), U2.8 (AD7)
Earth: C20.2, FB1.2, J2.3, J2.6
GND: C1.2, C2.1, C3.2, C4.2, C5.2, C6.1, C7.2, C8.2, C10.2, C11.2, C13.1, C14.2, C15.2, C16.2, C17.2, C18.2, C19.2, C21.2, C22.2, C23.2, FB1.1, J1.a39 (GND), J1.b2 (GND), J1.b16 (GND), J1.b22 (GND), J1.b28 (GND), J1.b34 (GND), J1.b39 (GND), J1.c39 (GND), J3.6, J4.a39 (GND), J4.b2 (GND), J4.b16 (GND), J4.b22 (GND), J4.b28 (GND), J4.b34 (GND), J4.b39 (GND), J4.c39 (GND), JP1.2 (B), JP2.2 (B), R1.2, R3.1, U1.6 (NC), U1.9 (NC), U1.10 (A16), U1.24 (GND), U1.30 (CE), U2.1 (VSSOSC), U2.18 (PSPCFG3), U2.23 (VSSPLL), U2.24 (VSSRX), U2.29 (VSSTX), U2.32 (VSSTX), U2.45 (A14/PSPCFG1), U2.46 (VSS), U2.62 (VSS), U3.2 (GND), U4.4 (GND), U4.16 (GND), U4.24 (GND), U4.36 (GND), U5.1 (GND), Y1.2, Y1.4
unnamed: C20.1, R8.2, R9.2
unnamed: TP6.1, U4.34 (I/O)
unnamed: C5.1, R2.1, R4.2, TR1.7 (C_RD)
unnamed: R9.1, TR1.10 (C_RX)
unnamed: C16.1, R6.2, TR1.2 (C_TD)
unnamed: R8.1, TR1.15 (C_TX)
unnamed: C3.1, U2.3 (OSC1), Y1.3
unnamed: C4.1, U2.2 (OSC2), Y1.1
unnamed: R1.1, U2.16 (RBIAS)
unnamed: C10.1, U2.63 (VCAP)
R/~W: J1.c8 (R/~W), J4.c8 (R/~W), U2.51 (SI/RD/R~W), U4.28 (I/O)
SIZ0: J1.b9 (SIZ0), J4.b9 (SIZ0), U4.25 (I/O)
SIZ1: J1.a9 (SIZ1), J4.a9 (SIZ1), U4.27 (I/O)
~AS: J1.c9 (~AS), J4.c9 (~AS), U4.23 (I/O)
~DSACK0: J1.b8 (~DSACK0), J4.b8 (~DSACK0), U4.30 (I/O)
~DSACK1: J1.a8 (~DSACK1), J4.a8 (~DSACK1), U4.31 (I/O)
~DS: J1.b6 (~DS), J4.b6 (~DS), U4.33 (I/O)
~IRQ1: J1.c4 (~IRQ1), J4.c4 (~IRQ1), U4.44 (I/O)
~IRQ2: J1.b4 (~IRQ2), J4.b4 (~IRQ2), U4.43 (I/O)
~IRQ3: J1.a4 (~IRQ3), J4.a4 (~IRQ3), U4.42 (I/O)
~NUBUS: J1.c2 (~NUBUS), J4.c2 (~NUBUS)
~RESET: J1.a12 (~RESET), J4.a12 (~RESET), U4.39 (I/GCLR)

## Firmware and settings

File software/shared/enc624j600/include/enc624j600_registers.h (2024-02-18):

/*
Register definitions for Microchip ENC624J600 Ethernet controller

Copyright (C) 2023-2024 Richard Halkyard

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
You should have received a copy of the GNU General Public License along with
this program.  If not, see <https://www.gnu.org/licenses/>.
*/

#ifndef ENC624J600_REGISTERS_H
#define ENC624J600_REGISTERS_H

#define ENC624J600_MEM_END ((unsigned short) 0x6000)

#define BIT(n) (1 << (n))
#define BITS(n) (BIT((n)+1)-1)

/*
Accessor macros for ENC624J600 registers:

  base: the base address of the ENC624J600
  reg_offset: the address of the register in the ENC624J600's memory map
  value: a 16-bit value to write to the register

Note that for some reason the datasheet's register table for the 16 bit PSP bus
register map gives register addresses as *word* rather than byte offsets. The
address map for the 8 bit bus gives byte offsets.
*/

/* Create a word pointer from a register */
#define ENC624J600_REG(base, reg_offset) \
  ((volatile unsigned short *)((base) + (reg_offset)))

/* Create a byte pointer from a register */
#define ENC624J600_REG8(base, reg_offset) \
  ((volatile unsigned char *)((base) + (reg_offset)))

/* Write a 16-bit value to a register*/
#define ENC624J600_WRITE_REG(base, reg_offset, value) \
  (*ENC624J600_REG((base), (reg_offset)) = (value))

/* Read a 16-bit value from a register */
#define ENC624J600_READ_REG(base, reg_offset) \
  (*ENC624J600_REG((base), (reg_offset)))

/* Write an 8-bit value to a register */
#define ENC624J600_WRITE_REG8(base, reg_offset, value) \
  (*ENC624J600_REG8((base), (reg_offset)) = (value))

/* Read an 8-bit value from a register */
#define ENC624J600_READ_REG8(base, reg_offset) \
  (*ENC624J600_REG8((base), (reg_offset)))

/*
The ENC624J600 has special registers that allow individual bits of certain
registers to be set or cleared, saving us a read-modify-write cycle. Note that
while the bit-set and -clear registers are at a fixed offset from the main
registers, not all registers can be manipulated in this way!
*/

/*
Set bits in a register using the set-bit register at reg_offset + 0x100

Equivalent to (but faster than):
  unsignd short tmp = ENC624J600_READ_REG(base, reg_offset);
  tmp |= bitfield
  ENC624J600_WRITE_REG(base, reg_offset, tmp);
*/
#define ENC624J600_SET_BITS(base, reg_offset, bitfield) \
  ENC624J600_WRITE_REG(                                 \
      (base), (reg_offset) + ENC624J600_SET_BIT_REGISTER_OFFSET, (bitfield))

/*
Clear bits in a register using the clear-bit register at reg_offset + 0x180

Equivalent to (but faster than):
  unsigned short tmp = ENC624J600_READ_REG(base, reg_offset);
  tmp &= ~bitfield
  ENC624J600_WRITE_REG(base, reg_offset, tmp);
*/
#define ENC624J600_CLEAR_BITS(base, reg_offset, bitfield) \
  ENC624J600_WRITE_REG(                                   \
      (base), (reg_offset) + ENC624J600_CLEAR_BIT_REGISTER_OFFSET, (bitfield))

/*
As per best practice when connecting little-endian and big-endian devices (see
http://www.cpu-ns32k.net/files/AN591.pdf for a good explanation, albeit about
connecting a little-endian processor to big-endian peripherals), the ENC624J600
is connected to the 68k bus with its low and high bytes swapped. This means that
'stream of bytes' data (i.e. network packets) is addressed in the right order,
but word-length data has the wrong byte order.

For bitfields, this is taken care of in the bit definitions below (i.e. bit 15
in the datasheet is represented as bit 7, bit 0 as bit 8, etc.), but pointers
etc. will need to be byteswapped.

This makes register access a bit convoluted but it's much less of a performance
hit than having to swap the bytes in every network packet!

Some general rules for register access:
  - Always access bitfield registers as whole words and select bits and fields
    using the definitions below.

  - Use set-bit (register + 0x100) and clear-bit (register + 0x180) registers
    whenever possible - it's faster than a read-modify-write, and it avoids any
    risk of disturbing other data in the register.

  - Swap bytes when accessing whole-word registers such as pointers.

  - Swap bytes when reading the next-packet pointer and packet-length fields in
    the receive buffer.

  - Don't swap bytes when reading or writing packet data.
*/

/* Set-bit registers are 0x100 bytes offset from their corresponding register.
 */
#define ENC624J600_SET_BIT_REGISTER_OFFSET 0x100
/* Clear-bit registers are 0x180 bytes offset from their corresponding register
 */
#define ENC624J600_CLEAR_BIT_REGISTER_OFFSET 0x180

#define ETXST 0x7e00
#define ETXLEN 0x7e02
#define ERXST 0x7e04
#define ERXTAIL 0x7e06
#define ERXHEAD 0x7e08
#define EDMAST 0x7e0a
#define EDMALEN 0x7e0c
#define EDMADST 0x7e0e
#define EDMACS 0x7e10
#define ETXSTAT 0x7e12
#define ETXWIRE 0x7e14

#define EUDAST 0x7e16
#define EUDAND 0x7e18
#define ESTAT 0x7e1a
#define EIR 0x7e1c
#define ECON1 0x7e1e

#define EHT1 0x7e20
#define EHT2 0x7e22
#define EHT3 0x7e24
#define EHT4 0x7e26
#define EPMM1 0x7e28
#define EPMM2 0x7e2a
#define EPMM3 0x7e2c
#define EPMM4 0x7e2e
#define EPMCS 0x7e30
#define EPMOL 0x7e32
#define ERXFCON 0x7e34

#define MACON1 0x7e40
#define MACON2 0x7e42
#define MABBIPG 0x7e44
#define MAIPG 0x7e46
#define MACLCON 0x7e48
#define MAMXFLL 0x7e4a
#define MICMD 0x7e52
#define MIREGADR 0x7e54

#define MAADR3 0x7e60
#define MAADR2 0x7e62
#define MAADR1 0x7e64
#define MIWR 0x7e66
#define MIRD 0x7e68
#define MISTAT 0x7e6a
#define EPAUS 0x7e6c
#define ECON2 0x7e6e
#define ERXWM 0x7e70
#define EIE 0x7e72
#define EIDLED 0x7e74

#define EGPRDPT 0x7e86
#define EGPWRPT 0x7e88
#define ERXRDPT 0x7e8a
#define ERXWRPT 0x7e8c
#define EUDARDPT 0x7e8e
#define EUDAWRPT 0x7e90

/* WARNING: 8 bit registers!!! */
#define EGPDATA 0x7e80
#define ERXDATA 0x7e82
#define EUDADATA 0x7e84

/* PHY registers */
#define PHCON1  0x00
#define PHSTAT1 0x01
#define PHANA   0x04
#define PHANLPA 0x05
#define PHANE 0x06
#define PHCON2 0x11
#define PHSTAT2 0x1b
#define PHSTAT3 0x1f

/*
Register bit and field definitions. Not that because of the byte-swapped data
bus, the bit numbers here are are not the same as the datasheet!

Datasheet bit:  15  14  13  12  11  10  9   8   7   6   5   4   3   2   1   0
Our bit:        7   6   5   4   3   2   1   0   15  14  13  12  11  10  9   8
*/
/* ESTAT */
#define ESTAT_INT BIT(7)
#define ESTAT_FCIDLE BIT(6)
#define ESTAT_RXBUSY BIT(5)
#define ESTAT_CLKRDY BIT(4)
#define ESTAT_PHYDPX BIT(2)
#define ESTAT_PHYLNK BIT(0)
#define ESTAT_PKTCNT_SHIFT 8
#define ESTAT_PKTCNT_MASK 0xff00

/* EIR */
#define EIR_CRYPTEN BIT(7)
#define EIR_MODEXIF BIT(6)
#define EIR_HASHIF BIT(5)
#define EIR_AESIF BIT(4)
#define EIR_LINKIF BIT(3)
#define EIR_PKTIF BIT(14)
#define EIR_DMAIF BIT(13)
#define EIR_TXIF BIT(11)
#define EIR_TXABTIF BIT(10)
#define EIR_RXABTIF BIT(9)
#define EIR_PCFULIF BIT(8)
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

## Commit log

2023-11-11 rev0 boards
    [breakout.kicad_pcb, breakout.kicad_sch, mechanical.FCStd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]
2023-11-11 SE: fiddle some track positions for better fills
    [se.kicad_pcb]
2023-11-11 First pass at driver
2023-11-13 Schematic PDFs
    [pds.kicad_sch, se30.kicad_sch]
2023-11-14 Use correct address for SE board
2023-11-14 add missing breakout-board schematic
2023-11-14 Remove inadvertently included files
    [mechanical.FCStd]
2023-11-14 Ignore kicad project backups
2023-11-28 driver WIP
2023-11-30 Better notes on slot addresses
2023-12-05 Add spurious-interrupt errata
2023-12-06 Print address of globals at driver open breakpoint
2023-12-09 Keep track of link state, don't try to transmit with no link
2023-12-09 discard padding for 802.2 Type 1 frames on receive
2023-12-12 Move reset to later in the shutdown process
    sdOnDrivers triggers *before* network volumes are unmounted, this caused hangs on shutdown if a network volume was mounted. sdRestartOrPower runs right before restart or power-off which is much more suitable.
2023-12-13 Refactor a bunch of stuff
    - Make a bunch of function arguments const
    - Tidy up comments
    - Replace ad-hoc receive header processing with struct
    [enc624j600_registers.h]
2023-12-15 Fix broken FindPH
    The changes in eec45d1e9658bfd78ce5c77dff64bb0697503e72 caused FindPH to
    throw an error when trying to find an empty PH table slot.
2023-12-15 Get async transmit working
    - Preserve extra registers across IODone call
    - Acknowledge transmit interrupt *before* calling IODone
2023-12-16 Use registers for argument passing in a few places
    - Driver entrypoints, since this avoids having to convert between Apple
    and C ABI
    - enc624j600_read_rxbuf, since this is on the critical path in the
    ReadPacket/ReadRest callback
2023-12-17 Better hardware detection and error handling
    - Use user-data pointer register to positively identify that an
    ENC624J600 is present where we think it is
    - Check for and handle more errors during startup
    - Check for Gestalt and SlotManger traps before using them
    - Only try to start SE driver if running on an SE
2023-12-17 Correct addresses of memory-access registers
    [enc624j600_registers.h]
2023-12-18 SE: Inhibit byte strobes when not selected
    Bring into line with the SE/30 glue logic
2023-12-18 Driver build requires Universal Interfaces
2023-12-20 Replace load-time debug break with 'panic button'
2023-12-24 Fix typo in MIIRD register name
    [enc624j600_registers.h]
2023-12-24 Check device-ID bits as art of device detection
2023-12-25 Remove shutdown hook if driver gets closed
2023-12-25 Move debug panic-button break to after relocation
2023-12-28 Deregister shutdown handler if driver open fails
2024-01-03 formatting and clarity fixes
    [enc624j600_registers.h]
2024-01-16 Use board_defs for resource board ID
2024-01-17 Branch optimizations
    - Give branch-prediction hints on 'hot' paths
    - Use 'Jxx' branch instructions to make the assembler use the smallest
    possible branch offset
2024-01-17 Installer: add package for SE driver
2024-01-28 Rev1 hardware
    [breakout.kicad_pcb, breakout.kicad_sch, pds.kicad_sch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]
2024-02-17 SPISEL pulldown resistor should be 100K, not 10K
    [se.kicad_pcb, se.kicad_sch, se30.kicad_pcb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]
2024-02-17 Correct footprint for SST39SF010
    [se30.kicad_sch]
2024-02-17 Cleanup driver comments
2024-02-17 Assorted driver performance tweaks
    - Add branch annotations
    - Be less fussy about multicast address matching
    - Move SE vs. SE/30 conditional to compile time
2024-02-17 Return old EIE value when disabling interrupts
2024-02-17 Remove workaround for issue #3
    Rev1 hardware is done with a hardware fix for
    Issue #3. This significantly increases write
    performance, at the cost of breaking compatibility
    with rev0 hardware.
    Since only one set of rev0 boards was ever built,
    and they're mine, I think this is OK :)
2024-02-18 update schematics
    [breakout.kicad_pcb, se.kicad_sch, se30.kicad_sch]
2024-02-19 SE30: replace vertical breakout connector with right-angle
    [se30.kicad_sch]
2024-02-19 SE30: Remove delay buffer on /BxSEL lines
    [se30.kicad_sch]
2024-02-24 Mitigation for DSACK rise time issues
    In machines with multiple expansion cards, the additional parasitic capacitance
    on the DSACK lines may increase the signal rise time beyond acceptable limits,
    especially on accelerated systems. This may cause instability if a new bus
    cycle gets underway before DSACK has stabilised - such behavior was observed
    with an Interware 50MHz accelerator.
    As a mitigation for this, drive DSACK push-pull, and only tristate it when the
    *next* bus cycle starts. This allows us to positively drive DSACK high at the
    end of a bus cycle, rather than relying on the 1K pullup on the logic board.
2024-03-04 SE30: add missing trace
2024-04-06 Rewrite ringbuffer routines in assembly
    The previous routines to copy data from the receive ringbuffer were a
    mix of assembly and C. Rewrite as all assembly to reduce overhead in
    parameter passing.
2024-04-25 Breakout: use threaded inserts for mounting
    Resize mounting holes for use with Wurth 9774025360R threaded inserts.
    [breakout.kicad_pcb, breakout.kicad_sch]
2024-04-29 programROM: fix declrom probe behavior
    Probe routine was repeatedly probing slot+0xff0000 instead of probing
    the last 16 bytes of the slot as intended.
2024-07-24 Update software status to mention A/UX driver
2024-11-25 Remove unused register debugging code
    Never fully implemented it, never ended up writing any tools to use it,
    don't really need it now that the driver is working.

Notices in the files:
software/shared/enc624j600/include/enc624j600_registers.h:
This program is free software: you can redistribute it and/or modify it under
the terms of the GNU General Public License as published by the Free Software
